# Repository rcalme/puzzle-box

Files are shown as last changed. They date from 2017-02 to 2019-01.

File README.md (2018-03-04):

# Custom Puzzle Box

This project is an attempt to build my skills in rapid prototyping, including laser cutting, 3D modeling and printing, and Arduino applications.

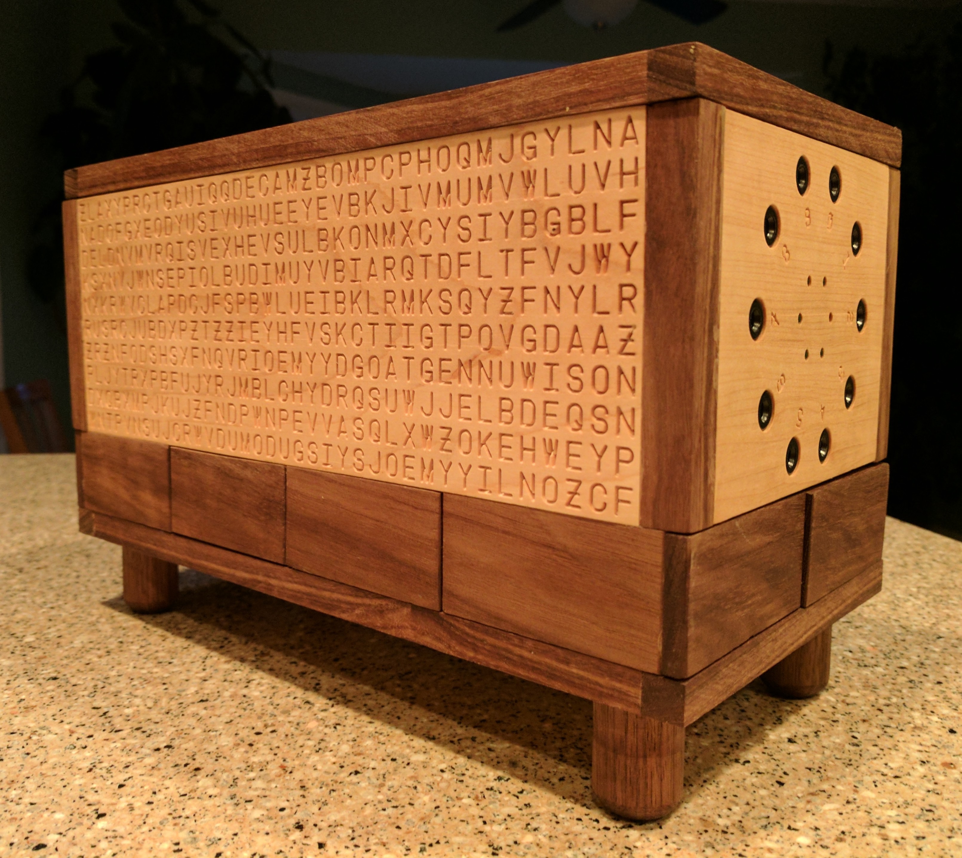
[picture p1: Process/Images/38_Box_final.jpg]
Final product


## Puzzles

* Magnet grid, with 30 positions, and 5 magnets (142,506 possible conbinations)
* Plug board with 10 numbered connectors, accepting 6 ordered pairs of digits (9,366,819 possible combinations)
* Screw panel, inaccessible without the correct tool
* Grille cipher, with double-sided grille
* Decryption cipher, with 5 unique two-sided gears (1,054,460 gear setup combinations)
  * 60 gear trio choices, 17,576 letter orientations
* Reversible drawer causing another drawer to open
* Hidden-in-plain-sight puzzles

## Video

Video of solution (http://www.youtube.com/watch?v=ibUV-bxcCZA)

## Design Process

You can see the progress in creating the physical box components on the [process readme].

[process readme]: </Process>

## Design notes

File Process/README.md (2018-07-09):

## Share your progress!
[Let me know](mailto:ryan.calme@gmail.com) if you've built one of these from my plans, and if so, what you needed to change so that I can make it better for others!

# Design and Manufacture Process

* This project was designed and built with mainly open-source softare.
* The specialized tools involved were available through the [TinkerMill] in Longmont, CO.

## Parts List
* See the [parts list]

## Hardware Used
* 80 Watt Laser Cutter ([Rabbit RL-80-1290])
* CNC Router ([Shopbot PRS Alpha])
* 3D Printer ([LulzBot Mini])
* Table Saw ([SawStop])
* Arduino ([Sparkfun Arduino Pro Mini 328 - 5V/16MHz])

## Software Used
* 3D Modelng ([SketchUp])
* 3D Slicing ([Cura])
* 2D Vector Design ([Inkscape])

## Puzzle Concepts

I did a lot of research on puzzles and puzzle box mechanisms while deciding what elements to include in this box.
Below are links to some content that inspired me:
* [Cipher gears]
* [Inverted drawer opening another]
* [Grille cipher]

## Initial prototype out of foam board:
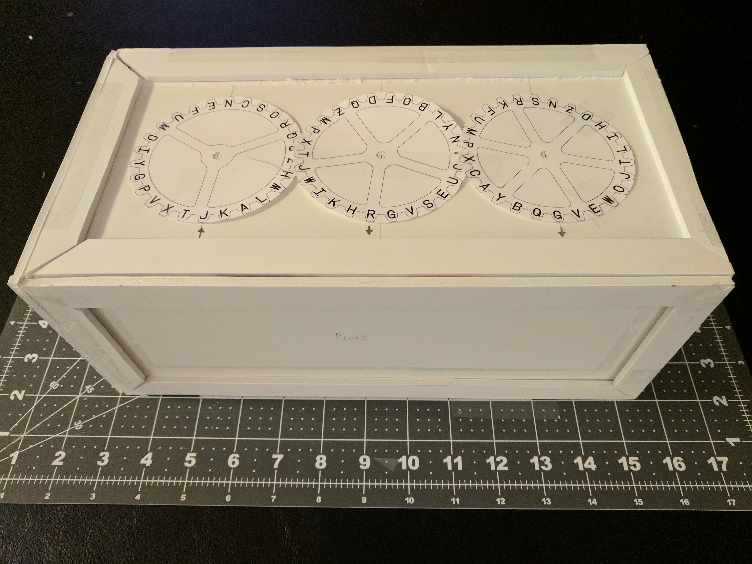
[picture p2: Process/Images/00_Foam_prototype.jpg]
Foam prototype
 

## Creating Cipher Gears

I wrote [Python code] to generate the order of the randomized letters on the five cipher gears, as well as to encrypt/decrypt messages.

The same was created as a [stand-alone web interface] by porting the code to Javascript to make it operable in a browser.

The gears themselves were first 3D printed, and later laser-cut in 1/4" red-stained maple, with the letters on the gear teeth engraved.
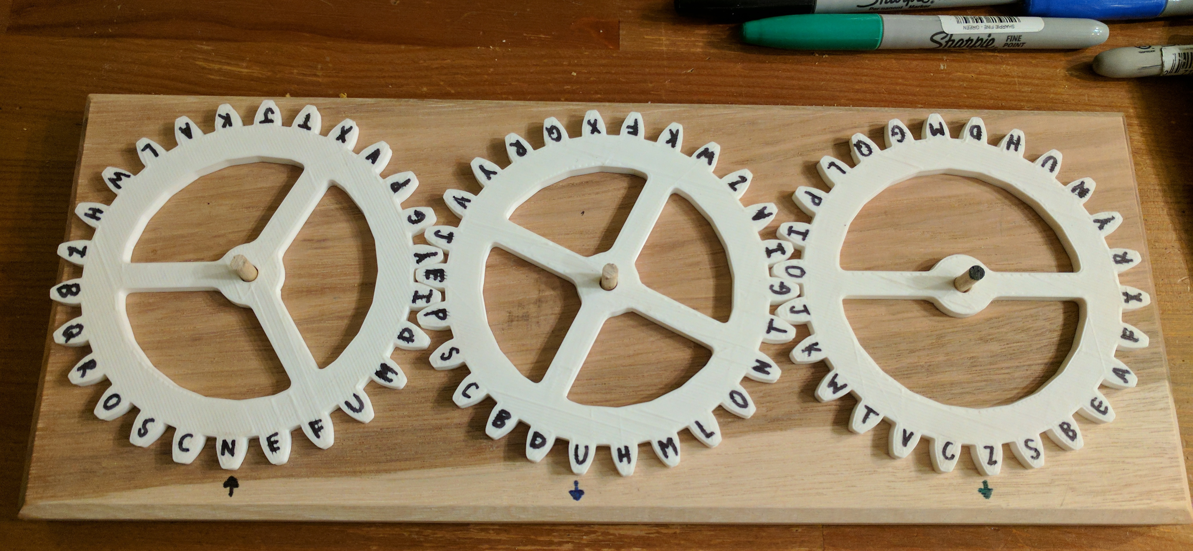
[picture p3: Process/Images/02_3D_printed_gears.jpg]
3D printed gears
 
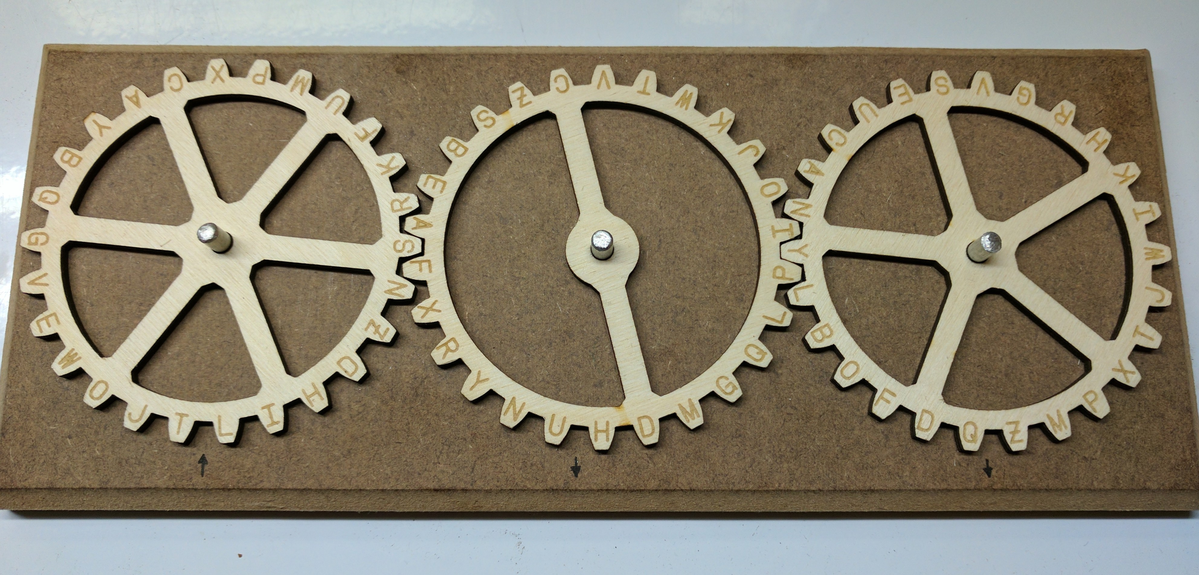
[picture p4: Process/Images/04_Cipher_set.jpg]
Cipher set
 
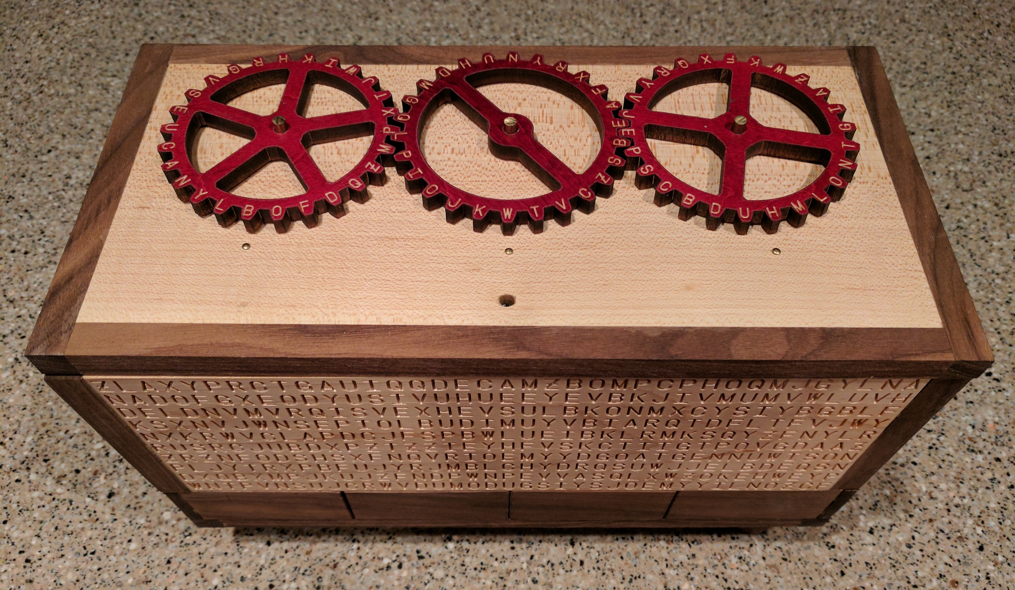
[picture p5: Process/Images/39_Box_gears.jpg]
Final gears
 
 
## Creating Magnet Puzzle

The magnet puzzle was always going to be a fixed-location puzzle, as the internal [reed switches] were wired in series.
The circuit is closed only when all switches were simultaneously closed.

The grid, and the symbols (in the [Magzetition font]) determine the locations of the five magnets to complete the hidden circuit, which itself supplies power to the [Arduino].

The outer layer is 1/4" maple, routed on a [ShopBot PRS Alpha], available at my local maker space.
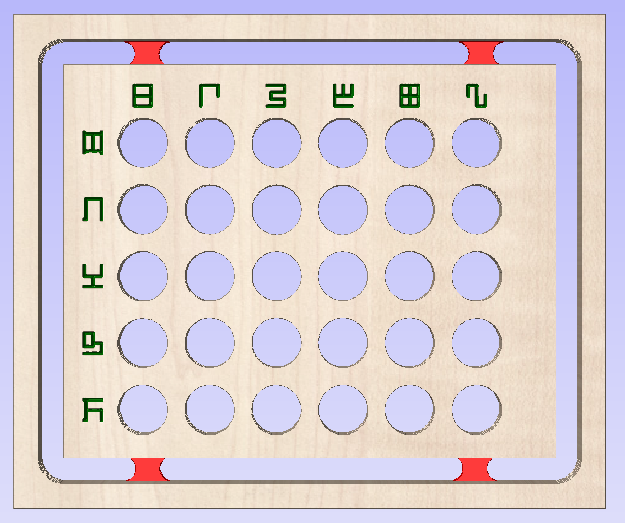
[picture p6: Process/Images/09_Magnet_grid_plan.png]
Magnet router plan
 
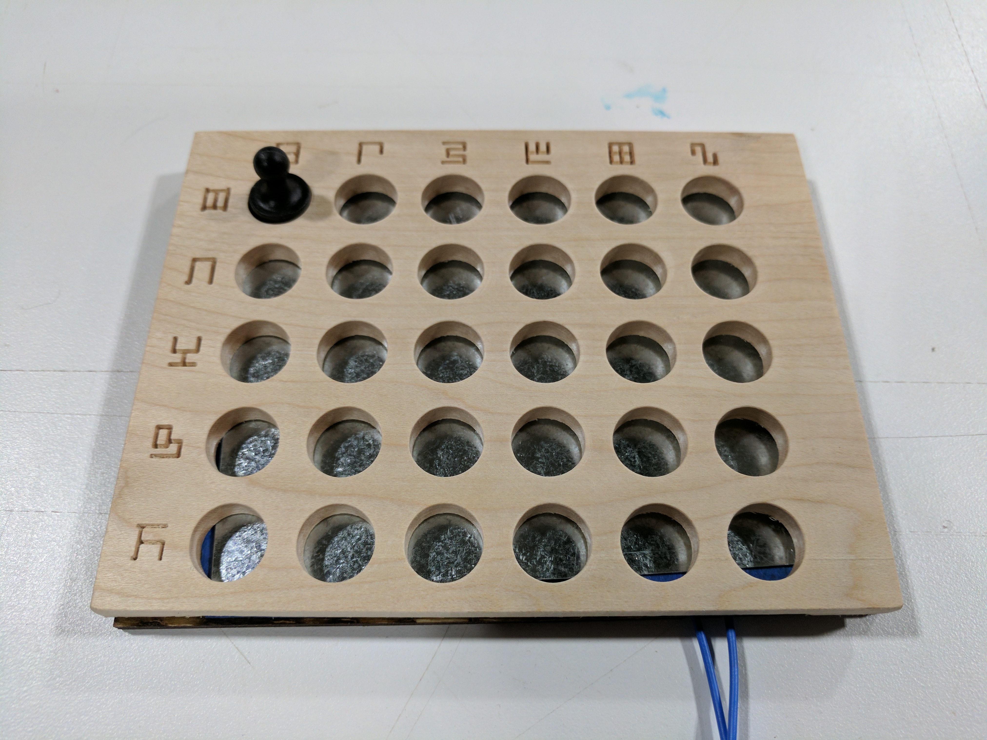
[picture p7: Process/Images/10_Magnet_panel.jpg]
Magnet puzzle outer
 

The inner layer is 1/8" Baltic birch, cut on an [80 watt Rabbit laser cutter], and wired up with these [mini reed switches].
 Magnet puzzle inner
 
## Creating Peg Board Puzzle

The peg board uses a jumper cable with banana connector ends, to detect the connection of any two-digit number pairs.
I set the code up to accept any combinations, and installed six LEDs to show progress when solving the puzzle's six ordered pairs of digits.

The [C++ code that probes this peg board] to detect any connection(s) using only 10 pins on an Arduino took some time to get right.

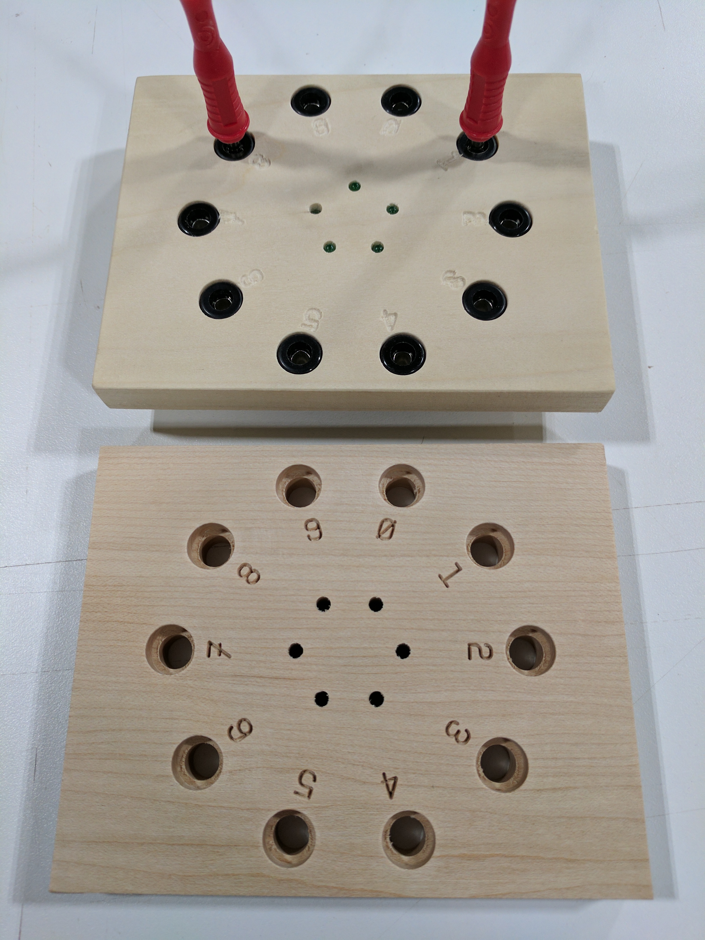
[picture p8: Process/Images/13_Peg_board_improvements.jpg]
Peg board improvements
 

## Creating the Back Panel Storage

The back panel is just an elaborate storage container for the [grille] mask plate.
The two faces are routed on a ShopBot, and sealed via security hex bit screws to make access difficult until the correct tool is located.

The grille itself is laser-cut out of two layers of 1/8" alder, sandwiching neodymium magnets.
The magnets ensure that the grille snaps into a single, specific position on the front of the box. When flipped to its 'B' side, the magnets are reversed, and again, the grille only snaps into a single (but different) location.

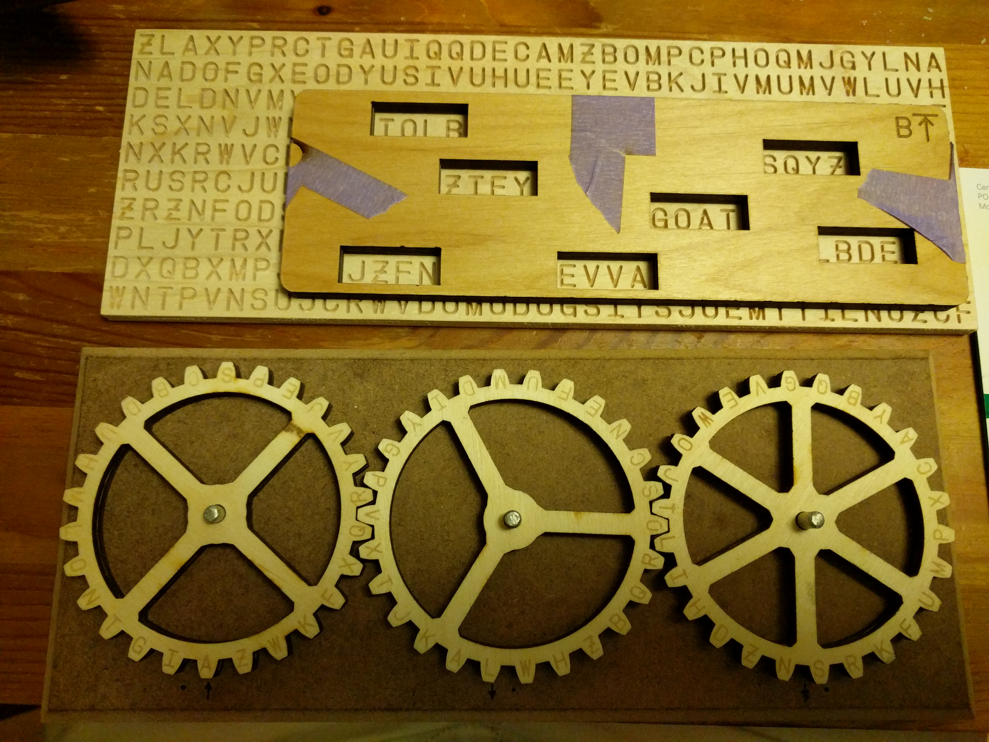
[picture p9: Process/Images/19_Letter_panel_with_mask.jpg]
mask plate in place
 
 
 ## Creating the Front Letter Panel
 
 The front letter panel is again routed on a ShopBot, with a field of random letters (in [Instruction font]).
 Only the letters highlighted with the grille are consequential (though encrypted).
 letter panel
 
 I wrote code to generate this letter field randomly, but consistently, as well as to calculate where to put the holes in the grille, such that when flipped from the 'A' side, to the 'B' side, there was no interference between the two patterns.

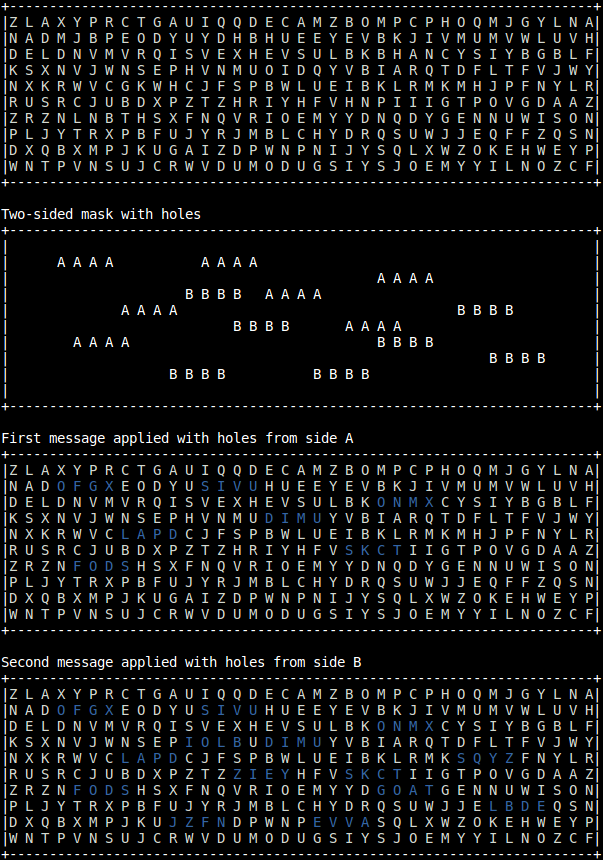
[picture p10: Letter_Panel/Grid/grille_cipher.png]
grille code output
 
 
 ## Creating the Drawers
 
 There are three operable drawers in the base of the box. 
 
 drawer assembly
 
 ### Left Drawer
 
 The left drawer is spring-loaded, and held in place by one of the legs of the box, which threads up through the base, into a hole in the drawer.
  When the leg is unscrewed, the drawer slides out.
  
 The drawer holds the magnets needed to complete the magnet puzzle on the left face.
 
 The threaded leg itself becomes a useful tool in solving the puzzle, as its tip is a star security bit, enabling access to the grille plate on the back of the box.
 
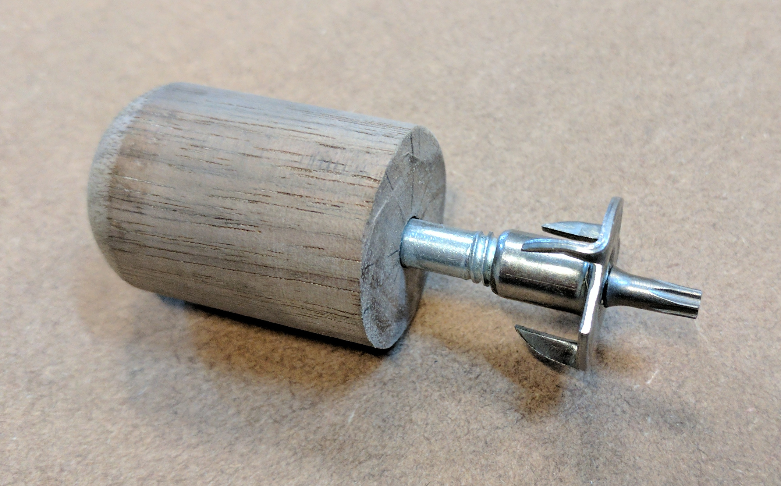
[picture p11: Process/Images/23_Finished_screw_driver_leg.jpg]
screw driver leg
 
 
 ### Front Drawer
 
 The front drawer holds two more cipher gears, needed to encrypt instructions for later in the puzzle.
 The drawer is released by turning the left drawer upside down, and pushing it back into its alcove.
 
 The latch mechanism was custom designed, and 3D-printed for this purpose.
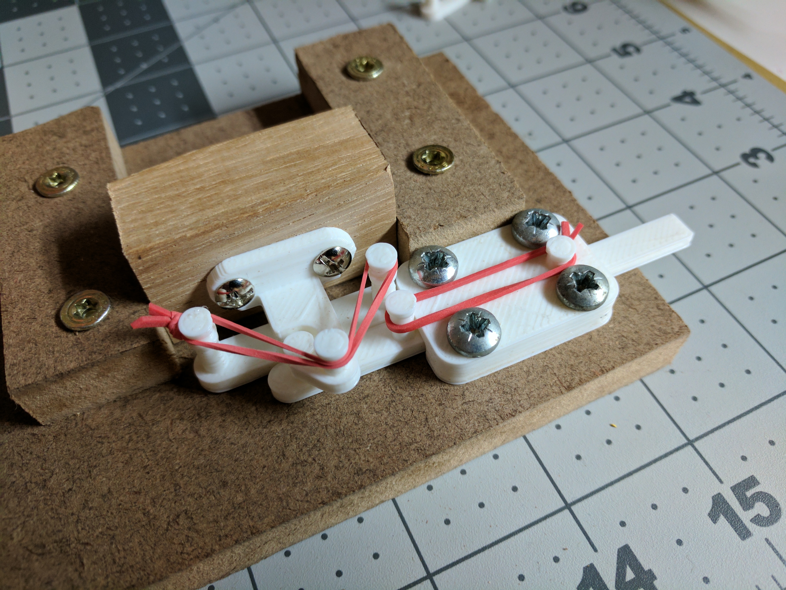
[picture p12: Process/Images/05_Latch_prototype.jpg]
latch mechanism
  
  
 ### Right Drawer
 
 The right drawer holds the banana jumper cable, and is released via a servo latch.
 The drawer is released as soon as the Arduino receives power (when the magnet puzzle is solved).
 
 ### Key Slider
 
 The key to unlock the box is finally accessible when it slides out the left side of the drawers via a servo.
 The sliding structure is made of two layers of laser-cut acrylic, and the brackets for the servo, and the slider are also custom designed and 3D-printed.
 
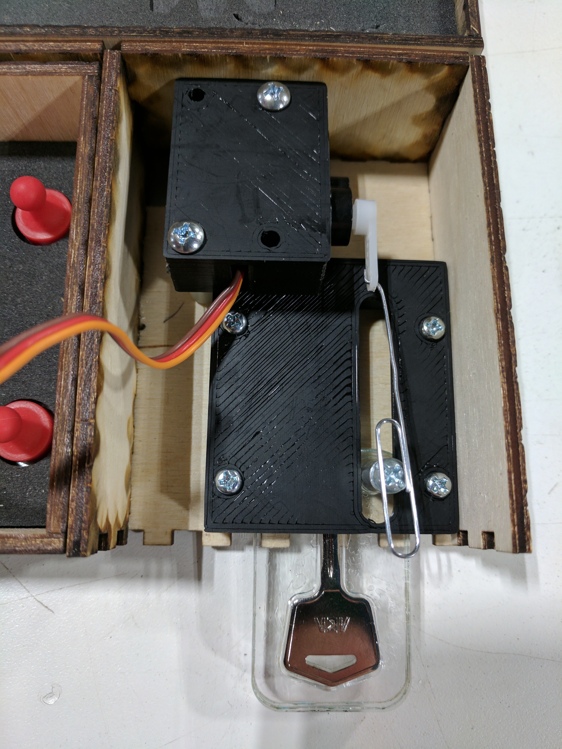
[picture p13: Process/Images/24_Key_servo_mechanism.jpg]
key slider
  
  
# Future improvements

I investigated the possibility of filling all the CNC-routed lettering with colored epoxy resin, and sanding it back down to flush with the face of the box. The results looked nice, but took quite a bit of time to get right.

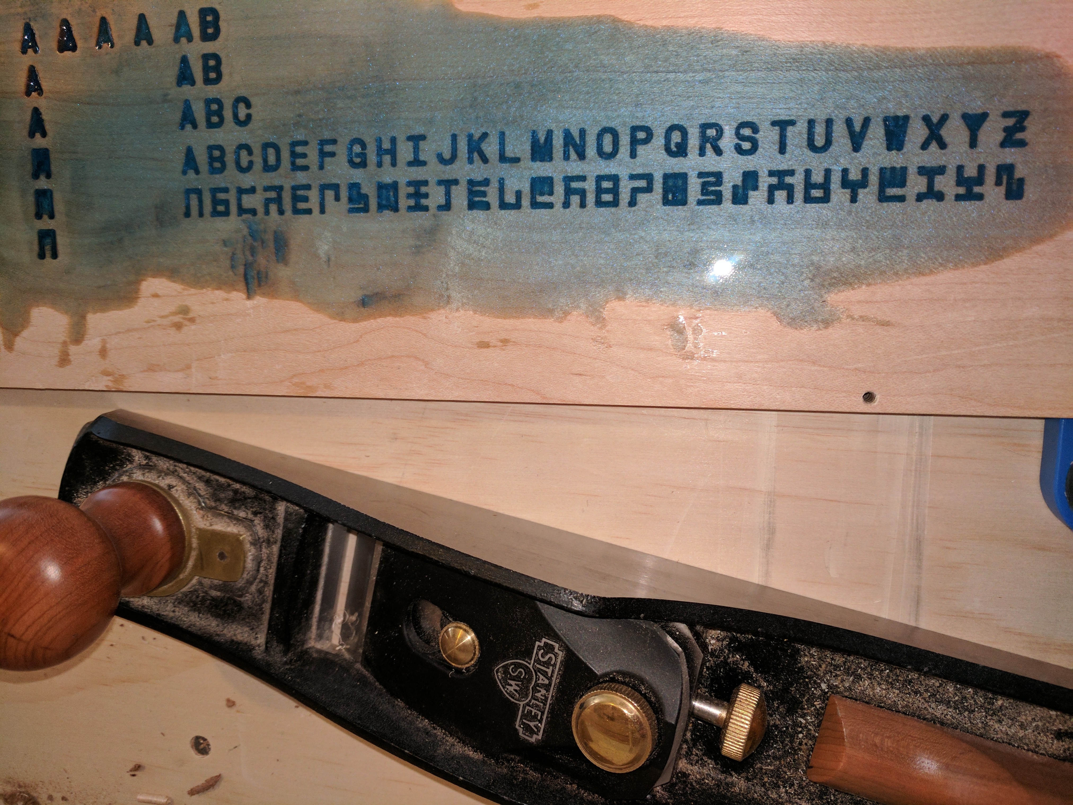
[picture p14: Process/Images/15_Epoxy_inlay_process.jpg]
epoxy resin
 
 epoxy finished
 
I also wrote the Arduino code to operate a speaker circuit with sound effects, but chose to cut this portion out due to lack of time, battery power draw, and available internal space.

   [Tinkermill]: <https://tinkermill.org>
   [Cipher gears]: <https://www.youtube.com/watch?v=hiOjqskDlS0>
   [Inverted drawer opening another]: <https://www.youtube.com/watch?v=foH1jnLvS_I>
   [Grille cipher]: <https://www.youtube.com/watch?v=tmgmOpaP_58>
   [Python code]: </Cipher_Gears/Translator/cryptex.py>
   [stand-alone web interface]: <https://rawgit.com/rcalme/puzzle-box/master/Cipher_Gears/Translator/cipherGears.html>
   [reed switches]: <https://en.wikipedia.org/wiki/Reed_switch>
   [Magzetition font]: <http://www.dafont.com/magzetician.font>
   [Instruction font]: <http://www.dafont.com/instruction.font>
   [Arduino]: <https://www.sparkfun.com/products/11113>
   [Sparkfun Arduino Pro Mini 328 - 5V/16MHz]: <https://www.sparkfun.com/products/11113>
   [ShopBot PRS Alpha]: <http://www.shopbottools.com/mProducts/prSalpha.htm>
   [80 watt Rabbit laser cutter]: <http://www.rabbitlaserusa.com/laser_RL1290.html>
   [Rabbit RL-80-1290]: <http://www.rabbitlaserusa.com/laser_RL1290.html>
   [mini reed switches]: <https://www.sparkfun.com/products/10601>
   [C++ code that probes this peg board]: </Arduino/Puzzle_Box>
   [grille]: <https://en.wikipedia.org/wiki/Grille_(cryptography)>
   [LulzBot Mini]: <https://www.lulzbot.com/store/printers/lulzbot-mini>
   [SawStop]: <http://www.sawstop.com>
   [SketchUp]: <http://www.sketchup.com>
   [Cura]: <https://www.lulzbot.com/cura>
   [Inkscape]: <https://inkscape.org/en>
   [parts list]: <PartsList.md>

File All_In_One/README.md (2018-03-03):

# All in one files

These files are prepared so that you can cut/print all the parts for a single tool in one go.
* **3D** includes a `.stl` file with all the necessary 3D-printed parts on one build plate.
* **Laser** includes a few `.dxf` files for laser cutting, one per material.
* **CNC** includes a `.dxf` file for a CNC router.

Assembly instructions can be found here

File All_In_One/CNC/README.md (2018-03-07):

# CNC Files

Depending upon your CNC, and software toolchain, you're likely to have to edit 
these files before you can send anything to your machine.

I cut this out of a 1x6 maple board, because it's what I had on hand.

The initial dimensions were 5.5" wide, 0.75" thick, and 48" long.

The thickest parts are 0.5", so the first pass is to use a flycutter bit to plane 
down the surface. This makes sure that it's both flat, and the correct thickness.

Cutting layout
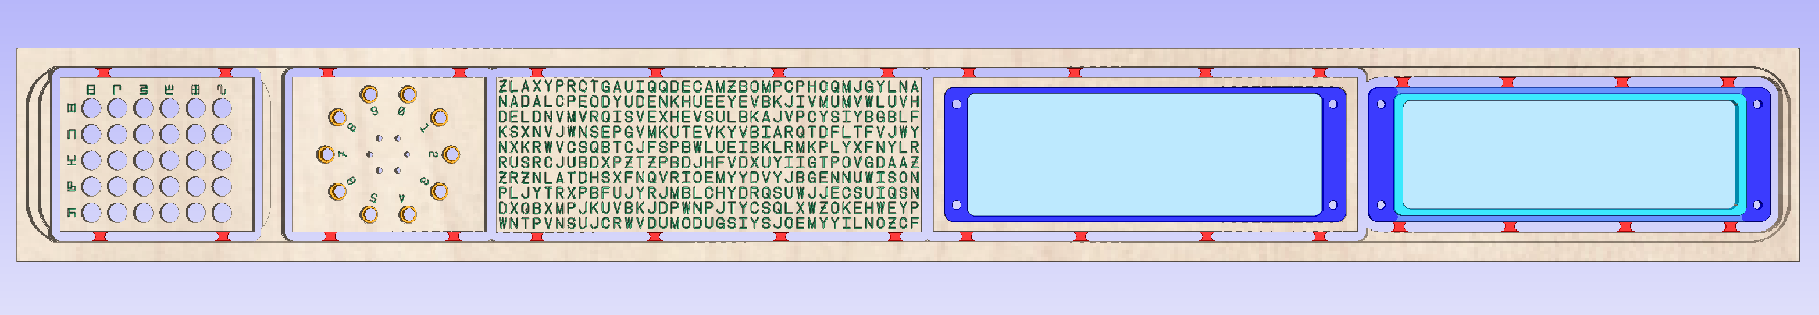
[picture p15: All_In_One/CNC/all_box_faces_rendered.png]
Rendered result


## Router Bits Used
Bit Type | Bit Diameter | Used For
---------|--------------|---------
Flycutter|2.0"          |Planing board surface to 0.5" and 0.25"
Endmill  |0.125" (1/8") |Cutting small through-holes (LEDs, screw holes)
Endmill  |0.25"  (1/4") |Cutting screw panel depths, cutting out panels
30° V-bit|0.125" (1/8") |Cutting letters (use a sharp bit, go very slowly)

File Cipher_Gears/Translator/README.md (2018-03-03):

# Encrypting/Decrpyting messages

The setup for encrypting and decrypting messages involves two parts:
1. Placing the gears in the right spoke order (2, 4, 5), for example
1. Turning each gear individually to match a key of an equal number of letters to the number of gears used.

An example [can be found here](https://rawgit.com/rcalme/puzzle-box/master/Cipher_Gears/Translator/cipherGears.html) (random seed is set to the default in this code).

[cipher.py](cipher.py) is provided to encrypt and decrypt arbitrary messages. Use it as follows:
```
> ./cryptex.py --gears 2 4 6 --key YAY --seed 12345 --encrypt "This is a secret message"
JBHQ HQYQ TADH JUTQ VMFH

> ./cryptex.py --gears 2 4 6 --key YAY --seed 12345 --decrypt "JBHQ HQYQ TADH JUTQ VMFH"
THIS ISAS ECRE TMES SAGE
```

**NOTE:** providing a random seed overrides the default, and will result in generated letter 
combination on the gears that differ from those in this git project. Take care to modify those files
before cutting parts if you intend to use a different seed.

You can print the orientation of the letters on the gears generated by this utility by adding the `--show` flag:
```
> ./cryptex.py --gears 2 4 6 --key YAY --seed 12345 --decrypt --show "JBHQ HQYQ TADH JUTQ VMFH"
2-spoke: YNZMSJBXUQRVHCDLEIGTAKPOFW
4-spoke: AJGLYPOEFUCBRVISKQWMXTHZND
6-spoke: YXQAPRHLMSIZENUJBFGTCKVDWO

THIS ISAS ECRE TMES SAGE

```

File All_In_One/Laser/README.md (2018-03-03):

## Laser Files

### Cipher Gears
The gears are cut from of 1/4" wood. I've used red-stained maple, as well as alder, which can be purchased 
in small quantity from [Colorado Heirloom](http://www.coloradoheirloom.com/products/160/Wood-Strip-br/-4-5-x-14-5-x-3/16-or-1/4)

### Drawers and Box Shell
This portion of the box is cut from 1/8" (3mm) birch plywood.

### Grille Cipher
The grille for the cipher is composed of two sandwiched 1/8" (3mm) pieces of wood, which can also be purchased from
[Colorado Heirloom](http://www.coloradoheirloom.com/wood-strip)

### Key Slider
This portion can be cut from 1/8" (3mm) acrylic, or wood.

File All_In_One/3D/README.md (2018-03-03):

## 3D-Printed Parts

This file contains all of the 3D-printed parts required.
* Latch hook for the right drawer
* Latch mechanism that allows the left drawer to open the center drawer
* Servo bracket
* Slider mechanism for the key drawer

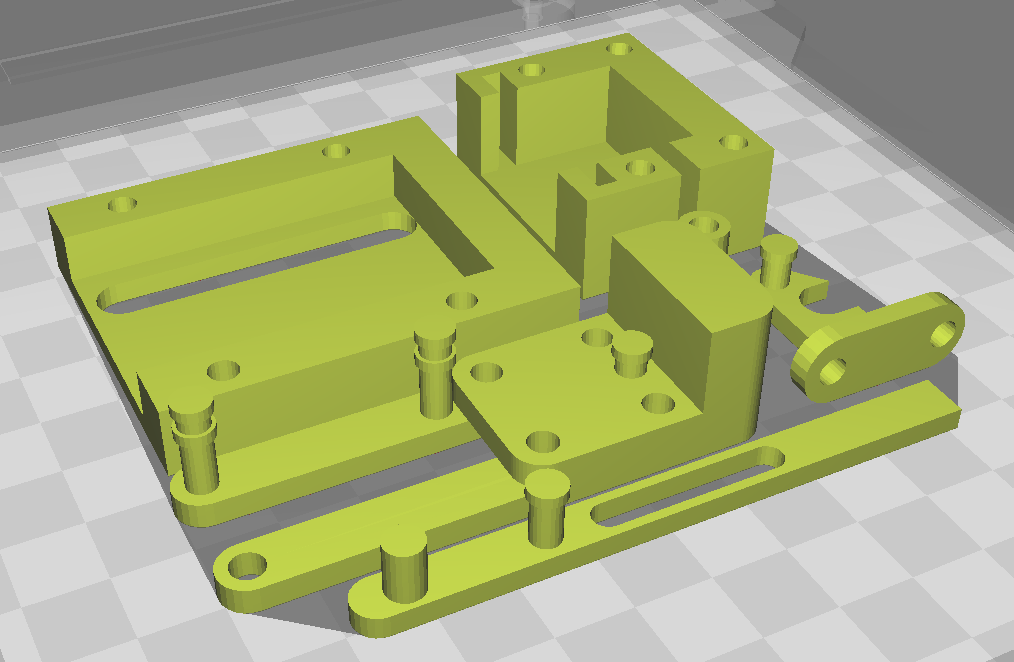
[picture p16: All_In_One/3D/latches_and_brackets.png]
Rendering of latches and brackets on build plate


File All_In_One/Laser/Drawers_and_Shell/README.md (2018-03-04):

## Drawers and Box Shell

These parts are all laid out on one sheet, but may have to be modified if you have a smaller form-factor laser cutter.

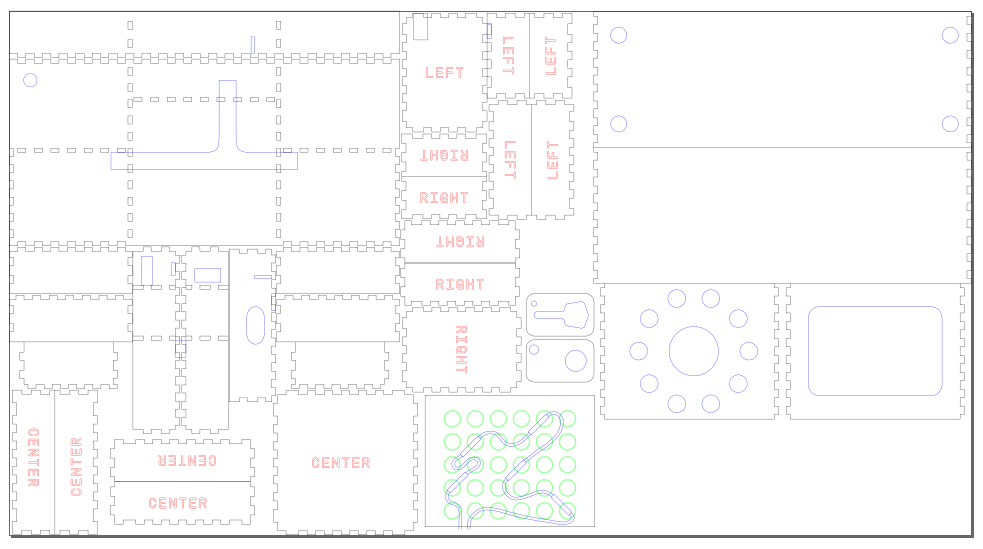
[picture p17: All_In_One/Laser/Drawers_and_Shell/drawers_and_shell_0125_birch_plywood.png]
Drawer parts


### Process
These pieces are pretty simple to cut and etch. I've made different colors for etching, cutting internal holes, and cutting external outlines.

I used the following laser power/speed settings:
* Etch
  * Speed: 300mm/s
  * Power: 18% of 80W machine (15 watts)
* Cut
  * Speed: 15mm/s
  * Power: 40% of 80W machine (32 watts)

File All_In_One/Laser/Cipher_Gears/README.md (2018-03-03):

## Cipher Gears

**NOTE:** These gears were generated with the code [here](/Cipher_Gears/Translator/cryptex.py), using a fixed random seed.
If you change the order of the letters by using a different random seed, obviously these 
files will need to be modified before cutting/etching.

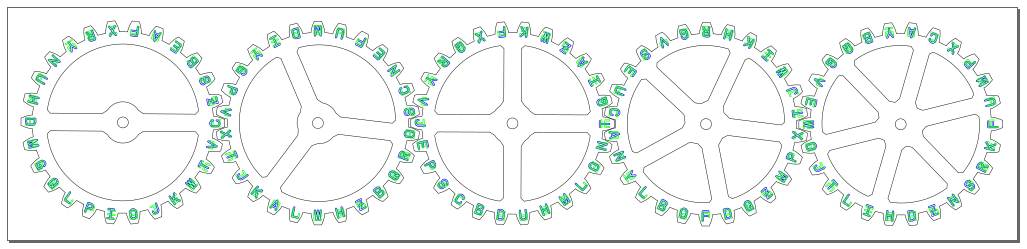
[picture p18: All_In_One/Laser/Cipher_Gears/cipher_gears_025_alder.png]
Cipher Gears


### Process
Since these are two-sided gears the order is pretty important:
1. (Optional) Cover both sides of the wood with low-tack painter's tape, or transfer paper to prevent charring
1. Etch one side of the gears (the two sides are different colors/layers)
1. Cut the gear outlines
1. Flip over the gears _without moving the frame from which they've been cut_, and making sure they remain in their same positions
1. Etch the other side of the gears

I used the following laser power/speed settings
* Etch
  * Speed: 400mm/s
  * Power: 18% of 80W machine (15 watts)
* Cut
  * Speed: 15mm/s
  * Power: 70% of 80W machine (56 watts)

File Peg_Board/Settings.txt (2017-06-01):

0.54"

Letters
  Bit: 0.125, 30 deg, 0.1 Depth, 4%/25%, 18K RPM, 0.15 ips, 0.2 ips plunge
  Depth: Flat @ 0.1
  Type: V-Carve  

LED
  Bit: 0.125
  Depth: Through
  Type: Pocker
  Passes: 4

Socket
  Bit: 0.25
  Depth: 0.2
  Type: Pocket
  Passes: 2

Socket Holes
  Bit 0.25
  Depth: Through
  Type: Pocket
  Passes: 4

Outer Cut
  Bit 0.25
  Depth: Through
  Type: Profile
  Tabs: 4 @ 0.1 tall, 0.25 wide

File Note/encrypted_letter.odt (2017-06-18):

I see that you have the tools to proceed The artifact awaits you above the home of those with cloven hooves

bgya hyxl kdry xoyl sahd asvl acpd qayv hyyz plbw xnhz dzbl vxar xiao ylsa sdoa awhy agym blsn wdja fyad jav

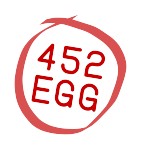
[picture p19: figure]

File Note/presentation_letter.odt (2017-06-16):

A unique item has fallen into my possession. I fear that I will not be able to keep it safe. You know too well the many who pursue my knowledge. I am giving it to you in the hopes that you will be able to keep it secret.

You should already have everything you need to unlock the secrets within. I trust in your skill - and your discretion.

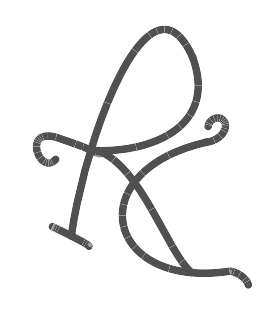
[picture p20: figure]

Our curiosity has brought us here. Only our wits can save us now.

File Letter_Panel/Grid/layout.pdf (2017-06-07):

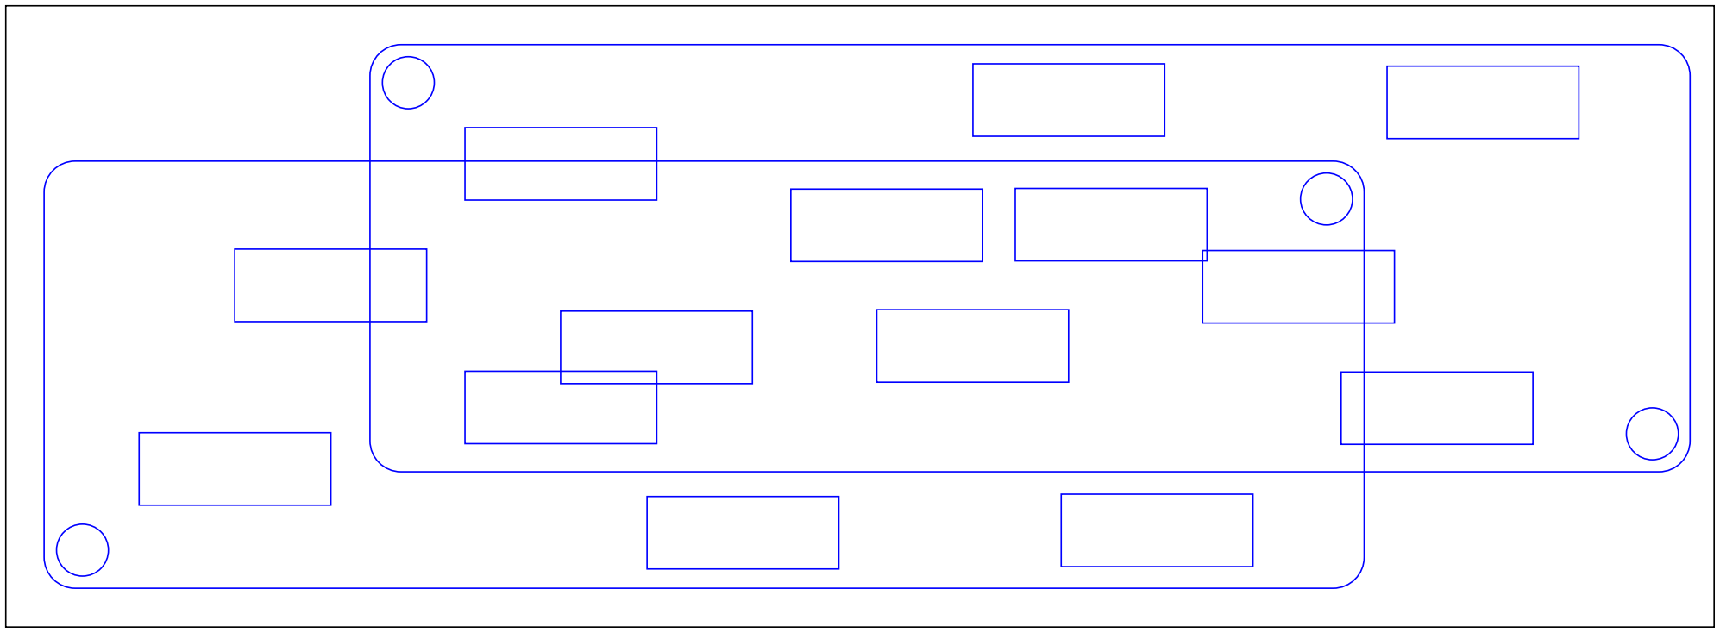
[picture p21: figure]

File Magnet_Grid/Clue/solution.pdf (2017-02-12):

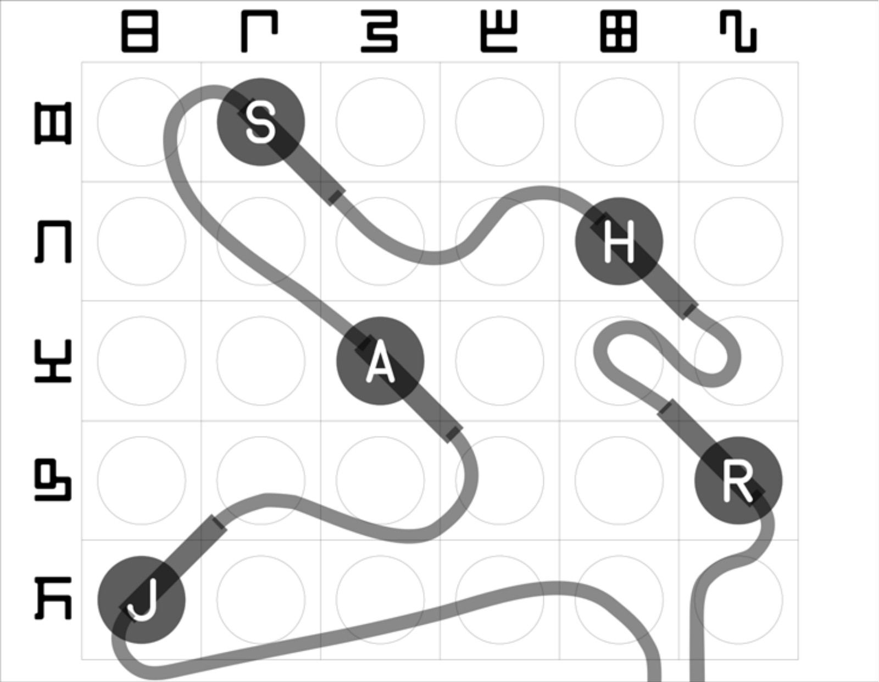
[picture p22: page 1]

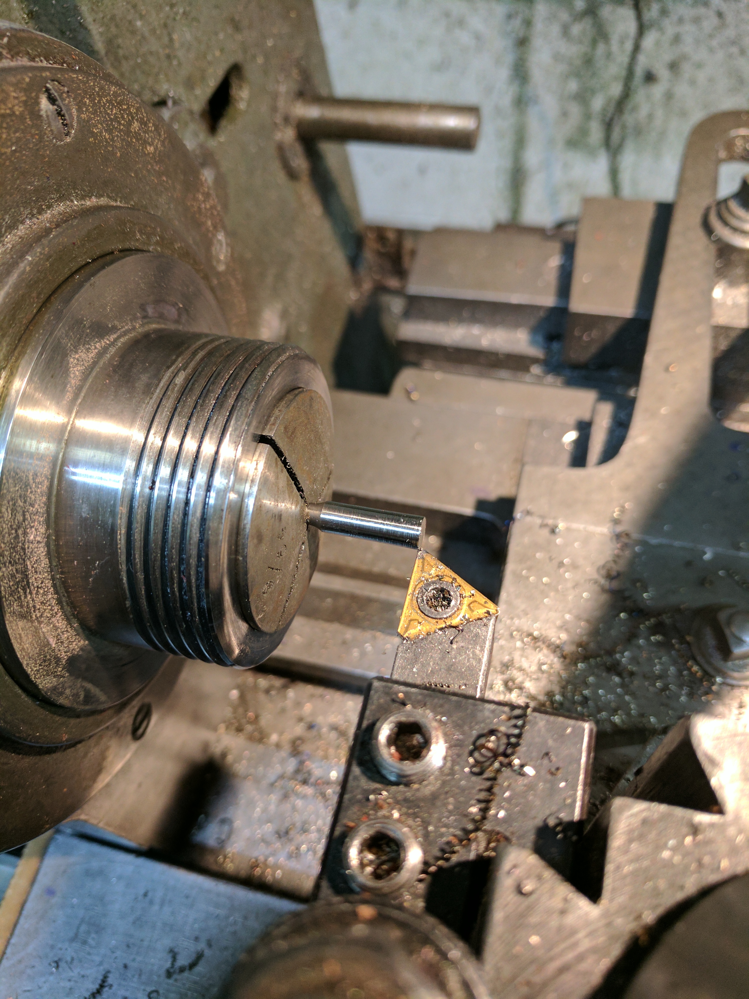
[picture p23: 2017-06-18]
Process/Images/20_Milling_driver_bit.jpg

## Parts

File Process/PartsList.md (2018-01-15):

# Parts List
All of the parts necessary to build this box should be listed here.

Everything ***should*** come to **under $250**, but it'll depend on the wood you choose, and your access to tools.

I'll admit that as of now, I've only built the one, but I documented everything pretty thoroughly as I went.
Feel free to contact me with questions.

## Parts
| Quantity | Cost Per	| Cost Total | Description | Number Used | Link | Note |
| --- | --- | --- | --- | --- | ---- | ---- |
| 1 | $15 | $15 | 48 Map Magnets | 5 | [Amazon](https://www.amazon.com/Magnets-48-Multi-Color-Magnetic-Style/dp/B014HKZA1W) | Comes with 12 each of 4 colors. | 
| 1 | $6 | $6 | 500 Small Rubber Bands | 2 | [Amazon](https://www.amazon.com/gp/product/B00Y16H9LM) |  | 
| 1 | $11 | $11 | Miniature Cam Lock | 1 | [Amazon](https://www.amazon.com/gp/product/B01HFNYH8A) | Comes with 2 keys. | 
| 1 | $19 | $19 | 10 Micro Servos | 2 | [Amazon](https://www.amazon.com/gp/product/B00ZEDRR3Q) | Come with horns, mounting screws. | 
| 1 | $8 | $8 | Neodynium Magnets | 4 | [Amazon](https://www.amazon.com/Linlinzz-Personalized-Multi-Use-Whiteboard-Refrigerators/dp/B01MZ6EJE2) | Comes with 35. | 
| 1 | $3 | $3 | 2 4xAA Battery Holders | 1 | [Amazon](https://www.amazon.com/gp/product/B00H8WI6HC) | Comes with 2. | 
| 1 | $8 | $8 | Security Bit Set | 1 | [Amazon](https://www.amazon.com/Mangocore-Security-Electric-Screwdrive-Magnetic/dp/B01I64IYJ0) | Will have to machine. | 
| 1 | $3 |  | 1/2" Security Screws | 4 |  | For back plate. Match the security bit you buy. | 
| 1 | $3 |  | Small Binding Posts | 4 |  | AKA "Chicago Screws". Security screws thread into these. | 
| 1 | $12 | $12 | 300 Multi-color 3mm LEDs | 5 | [Amazon](https://www.amazon.com/CO-RODE-Emitting-Assorted-300-Pack/dp/B00UWBJM0Q) | Any 3mm LEDs should suffice. | 
| 1 | $10 | $10 | 5v Arduino Pro Mini | 1 | [Sparkfun](https://www.sparkfun.com/products/11113) |  | 
| 5 | $2 | $10 | Magnetic Reed Switch | 5 | [Sparkfun](https://www.sparkfun.com/products/10601) |  | 
| 1 | $1 | $1 | Ribbon Cable | 1 | [Sparkfun](https://www.sparkfun.com/products/10649) | Doesn't have to be 10-wire. Helps with wire management. | 
| 2 | $5 | $10 | Banana Cable | 2 | [Digikey](https://www.digikey.com/product-detail/en/cal-test-electronics/CT2060-25-2/BKCT2060-25-2-ND) | One in the puzzle, one needed to reset. | 
| 10 | $1 | $7 | Banana Jacks | 10 | [Digikey](https://www.digikey.com/product-detail/en/cinch-connectivity-solutions-johnson/108-0903-001/J152-ND) | Discount if purchased in quantity. | 
| 1 | $3 | $3 | 3/16" Brass Rod | 1 | [Home Depot](https://www.homedepot.com/p/3-16-in-x-36-in-Zinc-Plated-Round-Rod-802287/204273957) | Doesn't have to be brass. Only need a few inches. | 
| 1 | $1 | $1 | Estucheon Pins | 3 | [Home Depot](https://www.homedepot.com/p/Everbilt-18-x-3-4-in-Brass-Escutcheon-Pins-0-5-oz-Pack-801294/204274028) | Any size/metal/length. | 
| 1 | $1 | $1 | Brass Washers | 3 | [Home Depot](https://www.homedepot.com/p/Everbilt-10S-Brass-Flat-Washer-10-Pack-802671/204276457) |  | 
| 1 | $1 | $1 | 1/4"x20 Hanger Bolt | 1 | [Home Depot](https://www.homedepot.com/p/Crown-Bolt-1-4-in-20-tpi-x-2-in-Stainless-Hanger-Bolt-48488/203537698) | Length will depend on legs. | 
| 1 | $1 | $1 | 1/4"x20 Tee Nut | 1 | [Home Depot](https://www.homedepot.com/p/Everbilt-1-4-in-20-tpi-x-5-16-in-Zinc-Plated-Tee-Nut-4-per-Pack-802301/204274194) |  | 
| 1 | $11 | $11 | Steel Sheet (Magnetic) | 1 | [Home Depot](https://www.homedepot.com/p/M-D-Building-Products-12-in-x-24-in-22-Gauge-Weldable-Sheet-56066/202091749) | Need 5"x5". | 
| 1 | $2 | $2 | Small Hinges | 2 | [Home Depot](https://www.homedepot.com/p/Everbilt-1-in-Zinc-Plated-Non-Removable-Pin-Narrow-Utility-Hinges-2-Pack-15161/202034166) | Your choice of size/style. | 

## Materials
| Quantity | Cost | Description | Link | Note |
| --- | ---- | --- | ---- | ---- |
| 1 | $5 | 1/4" Laser-etchable Wood | [Colorado Heirloom](http://www.coloradoheirloom.com/products/160/Wood-Strip-br/-4-5-x-14-5-x-3/16-or-1/4) | For gears. | 
| 1 | $5 | 1/8" Laser-etchable Wood | [Colorado Heirloom](http://www.coloradoheirloom.com/wood-strip) | For grille cipher sandwich) | 
| 1 | $12 | 1/4" Laser-safe Foam | [Foam Factory](http://www.thefoamfactory.com/closedcellfoam/cross-linked-polyethylene-foam.html) | Cross-Linked Polyethelene. For gear drawer insert. | 
| | | 1/2" Maple |  | For all other faces. | 
| | | 1/4" Maple |  | For magnet puzzle face. | 
| | | 1/2" Walnut |  | For border. | 
| | | 1" Walnut Dowel |  | For feet. | 
| | | 1/8" (3mm) Birch Plywood |  | For laser-cut drawers/interior. | 
| | | 1/8" Acrylic |  | For the key-holder - could also be wood. | 
      
## Consumables
| Item | Note |
| ---- | ---- |
| Patience | A lot. |
| Soldering Iron | |			
| Solder | |
| Hook-up Wire | |
| Heat-shrink Tubing | |
| 220 Ohm Resistors | For LEDs - Modify depending upon your LEDs. |
| Ballpoint Pen Springs | |
| USB FTDI Arduino Cable | [Sparkfun](https://www.sparkfun.com/products/9718) - To Program the Arduino. |
| Male 0.1" Headers | [Sparkfun](https://www.sparkfun.com/products/116)	|
| AA Batteries | |
| Assorted Screws | |
| Wood Glue | |

## Expensive Tools
| Item | I Used | Note |
| ---- | ---- | ---- |
|	3D Printer | [Lulzbot Mini](https://www.lulzbot.com/store/printers/lulzbot-mini) | Printed in [PLA](https://www.lulzbot.com/store/filament/polylite-pla) |
|	CNC Router | [ShopBot PRS Alpha](http://www.shopbottools.com/mProducts/prSalpha.htm) | Don't need a very large work surface for this project. |
|	Laser-etcher/cutter | [Rabbit Laser 80-Watt](http://www.rabbitlaserusa.com/laser_RL1290.html) | Cut/Engrave Settings are saved in files. |
|	Table Saw | [SawStop](http://www.sawstop.com/table-saws/by-model/industrial-cabinet-saw) | |
|	Metal Lathe | Generic | To turn the security bit down in diameter. |

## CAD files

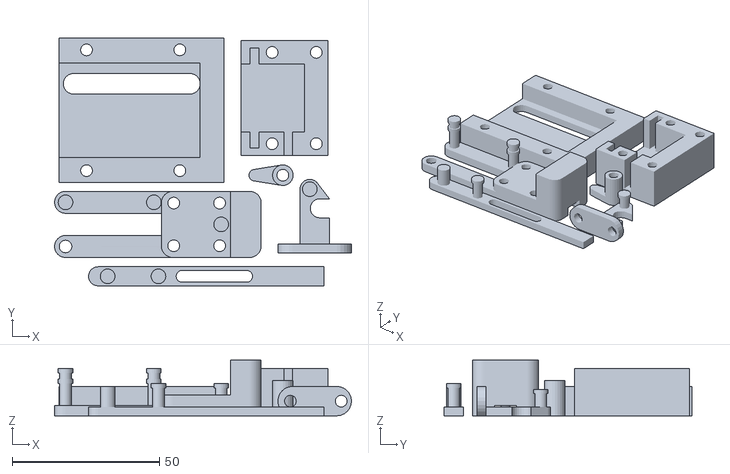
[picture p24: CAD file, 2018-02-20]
All_In_One/3D/latches_and_brackets.stl
100.9 x 84.1 x 18.9

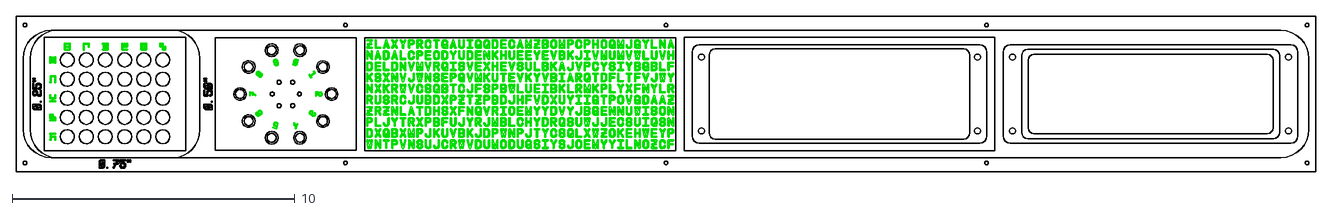
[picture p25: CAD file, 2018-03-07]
All_In_One/CNC/all_box_faces_075_maple.dxf
46.0 x 5.50

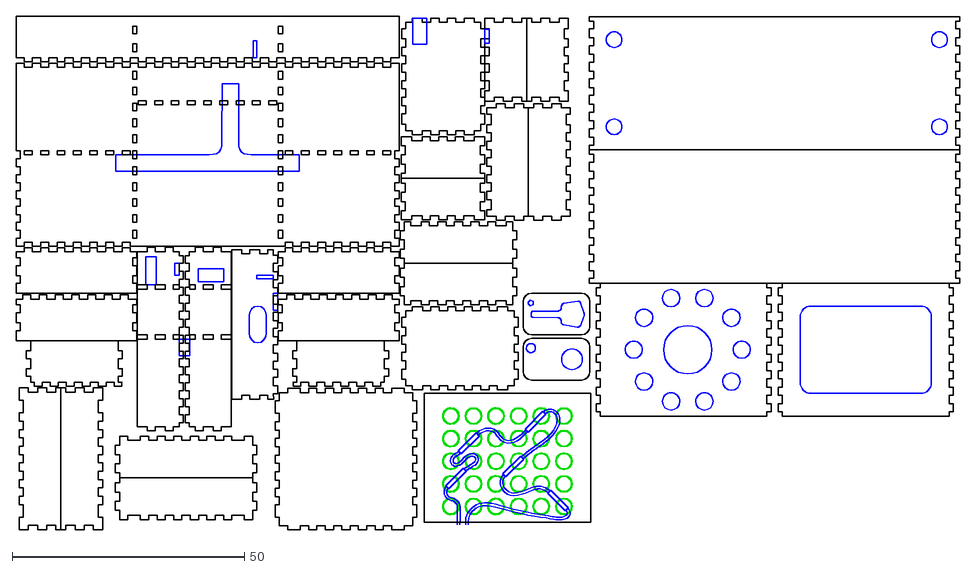
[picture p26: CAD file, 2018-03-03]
All_In_One/Laser/Drawers_and_Shell/drawers_and_shell_0125_birch_plywood.dxf
203.1 x 110.6

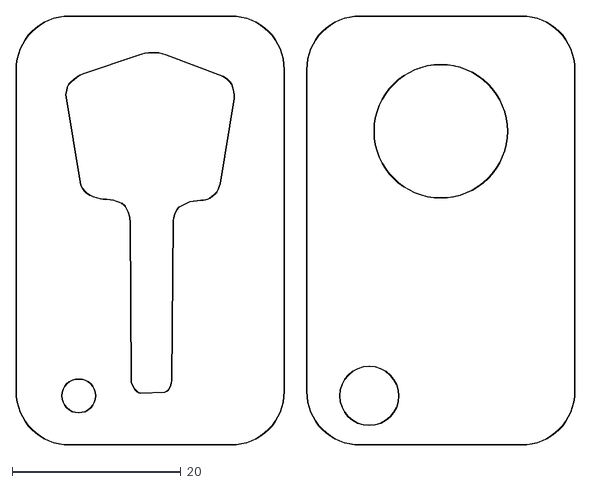
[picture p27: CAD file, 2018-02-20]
All_In_One/Laser/Key_Slider/key_slider_0125_acrylic.dxf
66.2 x 50.8

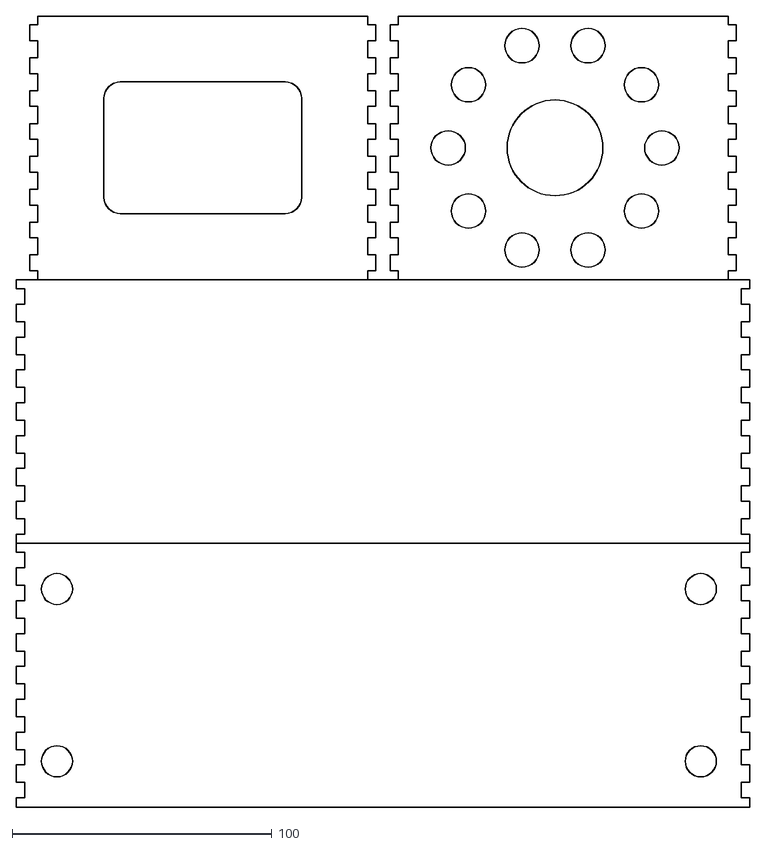
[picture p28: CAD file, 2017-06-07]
Box_Shell/box_shell.dxf
282.6 x 304.8

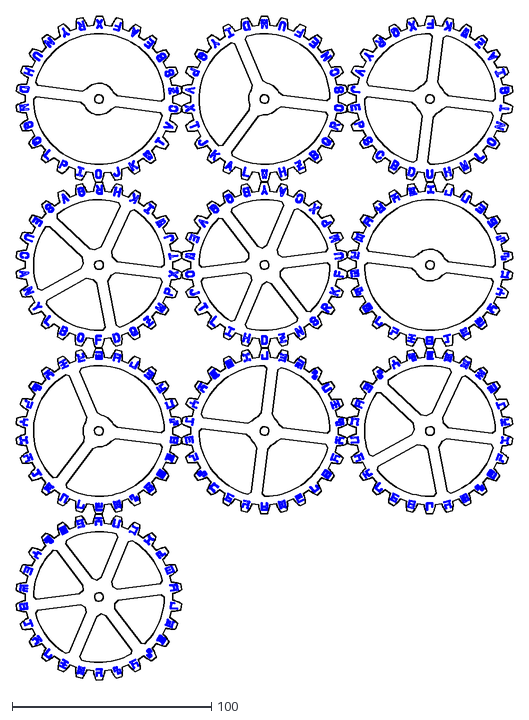
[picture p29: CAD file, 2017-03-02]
Cipher_Gears/All_Gears/all_gears.dxf
249.3 x 333.4

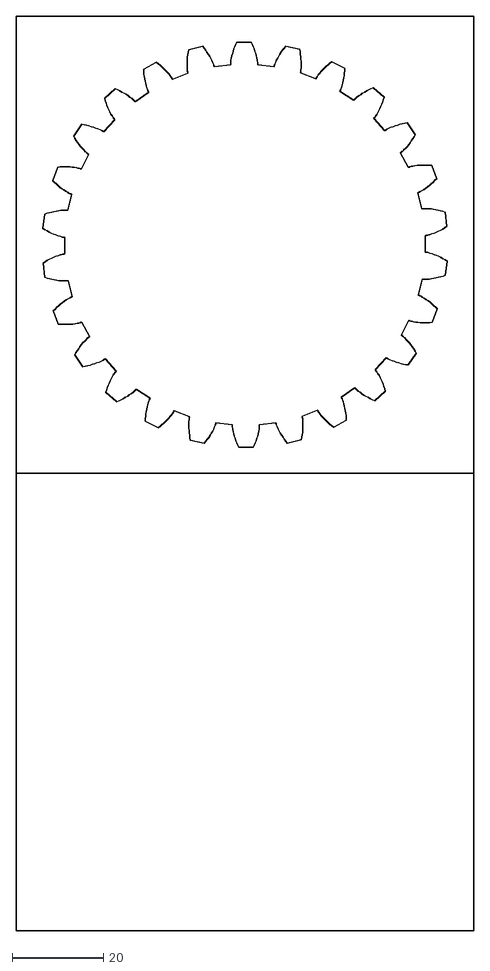
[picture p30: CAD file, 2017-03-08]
Cipher_Gears/Foam_Cutout/gear_cutout.dxf
100.3 x 200.6

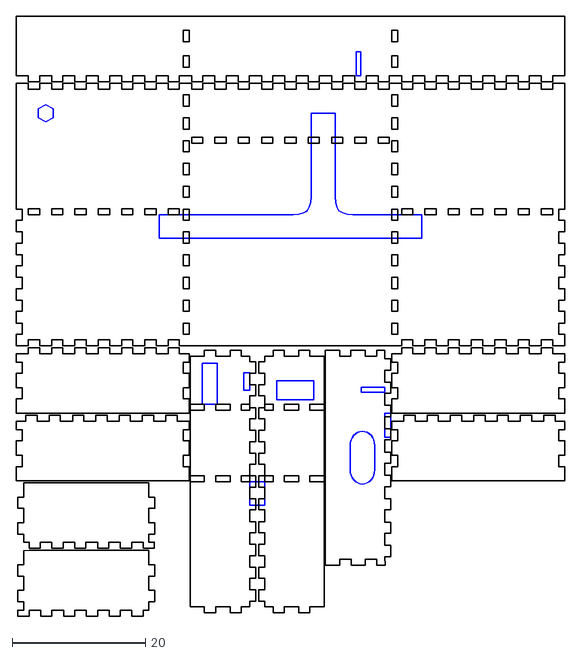
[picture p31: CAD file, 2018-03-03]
Drawers/Base/drawer_base.dxf
82.4 x 90.2

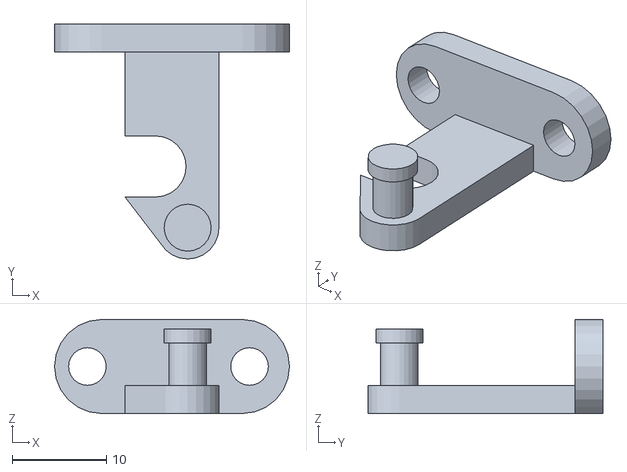
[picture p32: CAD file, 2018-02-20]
Drawers/Center/hook.stl
25.0 x 25.0 x 10.0

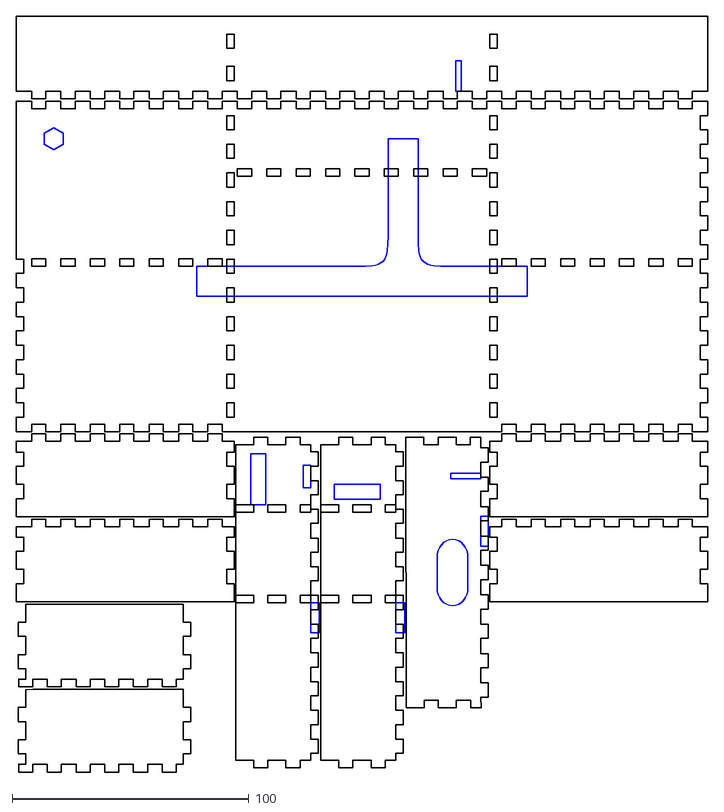
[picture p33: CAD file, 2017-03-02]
Drawers/Drawer_Base/drawer-base.dxf
292.1 x 319.5

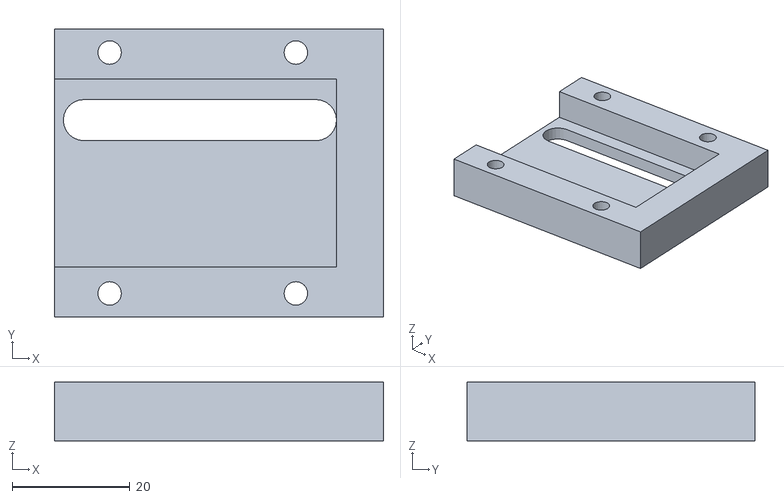
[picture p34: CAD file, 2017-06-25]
Drawers/Key/key_guide.stl
56.0 x 49.0 x 10.0

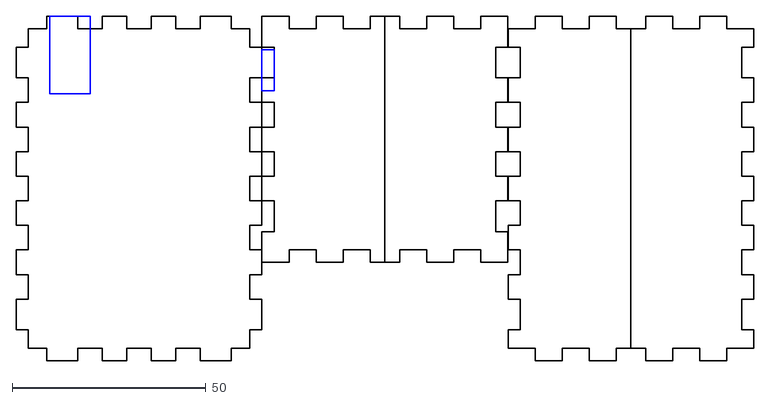
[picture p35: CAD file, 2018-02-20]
Drawers/Left/left_drawer.dxf
190.6 x 88.9

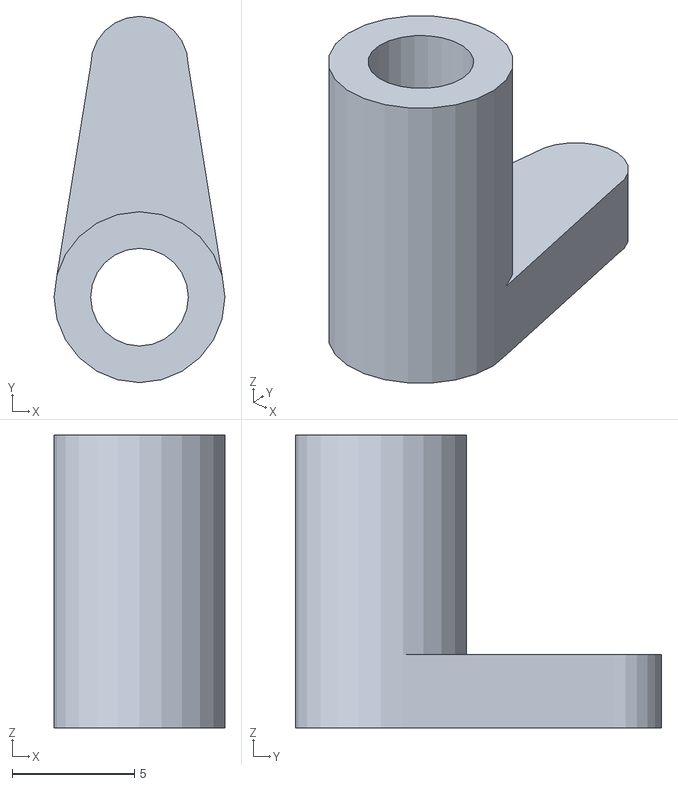
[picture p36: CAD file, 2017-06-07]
Drawers/Right/catch.stl
7.00 x 15.0 x 12.0

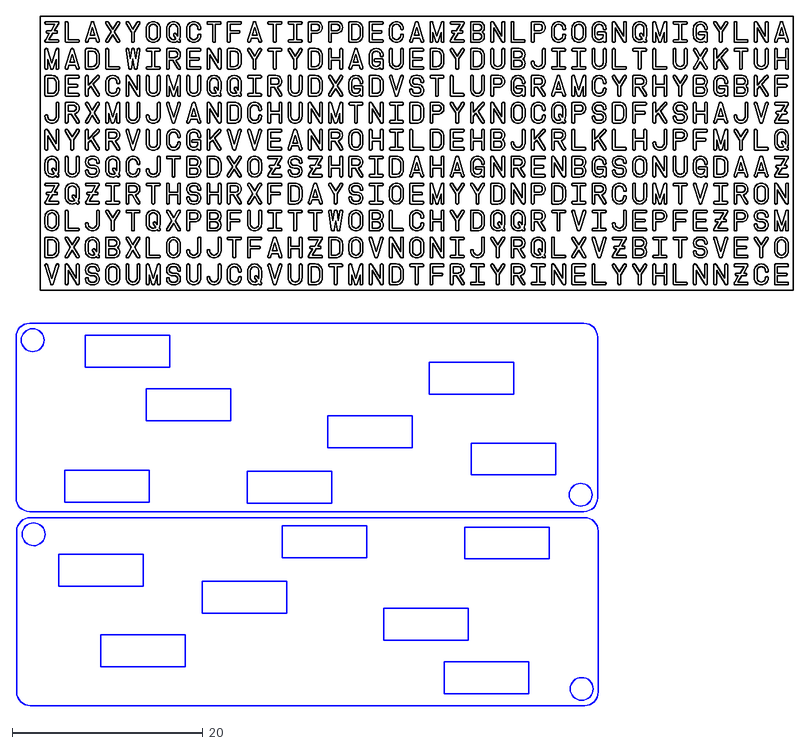
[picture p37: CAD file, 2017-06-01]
Letter_Panel/Grid/letter_grid.dxf
81.4 x 72.2

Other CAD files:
Cipher_Gears/Individual_Gears/6_spoke_3.5_inch.dxf
Letter_Panel/Inner/latch_test.dxf
Letter_Panel/Mask/letter_mask.dxf
Magnet_Grid/Internal/wire_route.dxf
Cipher_Gears/Individual_Gears/2_spoke_3.5_inch.dxf
Cipher_Gears/Individual_Gears/3_spoke_3.5_inch.dxf
Cipher_Gears/Individual_Gears/4_spoke_3.5_inch.dxf
Cipher_Gears/Individual_Gears/5_spoke_3.5_inch.dxf
Drawers/Center/center_drawer.dxf
Drawers/Center/center_latch.skp
Drawers/Center/guide.stl
Drawers/Center/slider.stl
Drawers/Key/key.dxf
Drawers/Key/key_mechanism.skp
Drawers/Key/servo_bracket.stl
Drawers/Right/catch.skp
Drawers/Right/right_drawer.dxf
Letter_Panel/Inner/mask_plate.dxf
Letter_Panel/Mask/Old/latch_test.dxf
Letter_Panel/Mask/Old/mask_plate.dxf
Peg_Board/peg_board.dxf
Peg_Board/peg_board_middle_layer.dxf
Rendering/Full_Rendering.skp
Screw_Panel/screw_plate.dxf

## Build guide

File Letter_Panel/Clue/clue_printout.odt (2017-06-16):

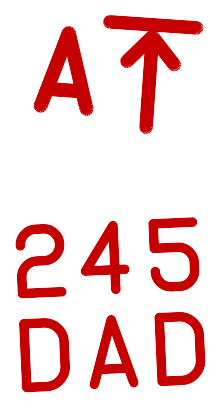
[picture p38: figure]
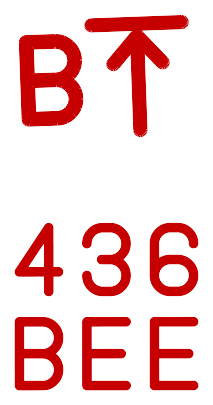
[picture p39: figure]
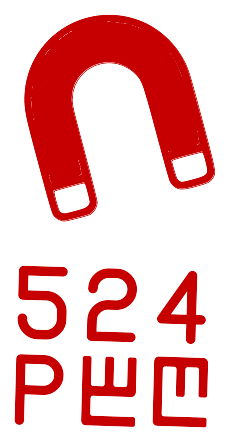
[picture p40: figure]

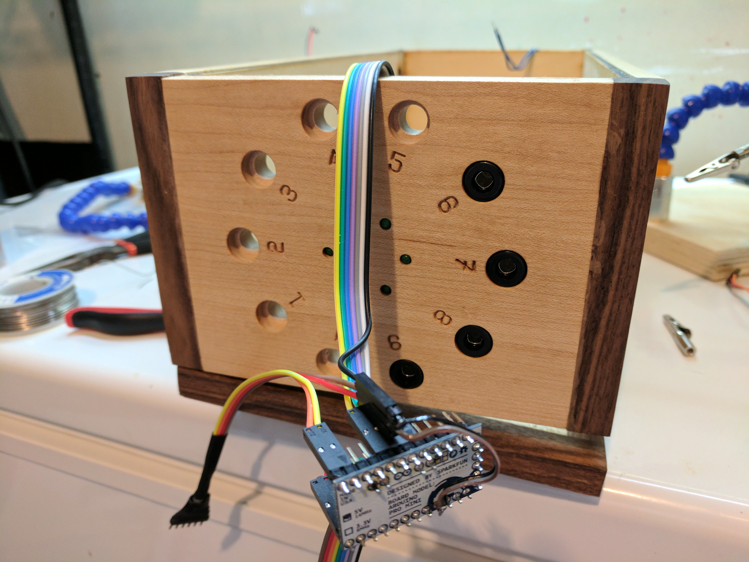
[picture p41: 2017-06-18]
Process/Images/32_Wiring_peg_board.jpg

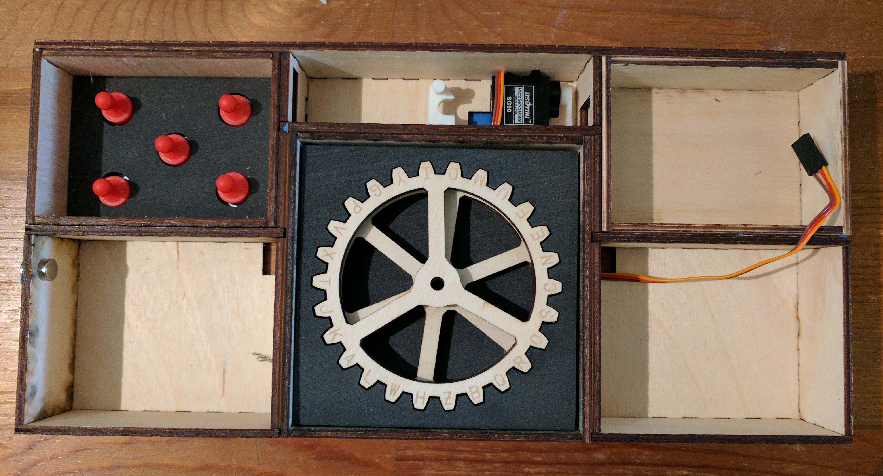
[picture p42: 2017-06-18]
Process/Images/08_Drawer_assembly.jpg

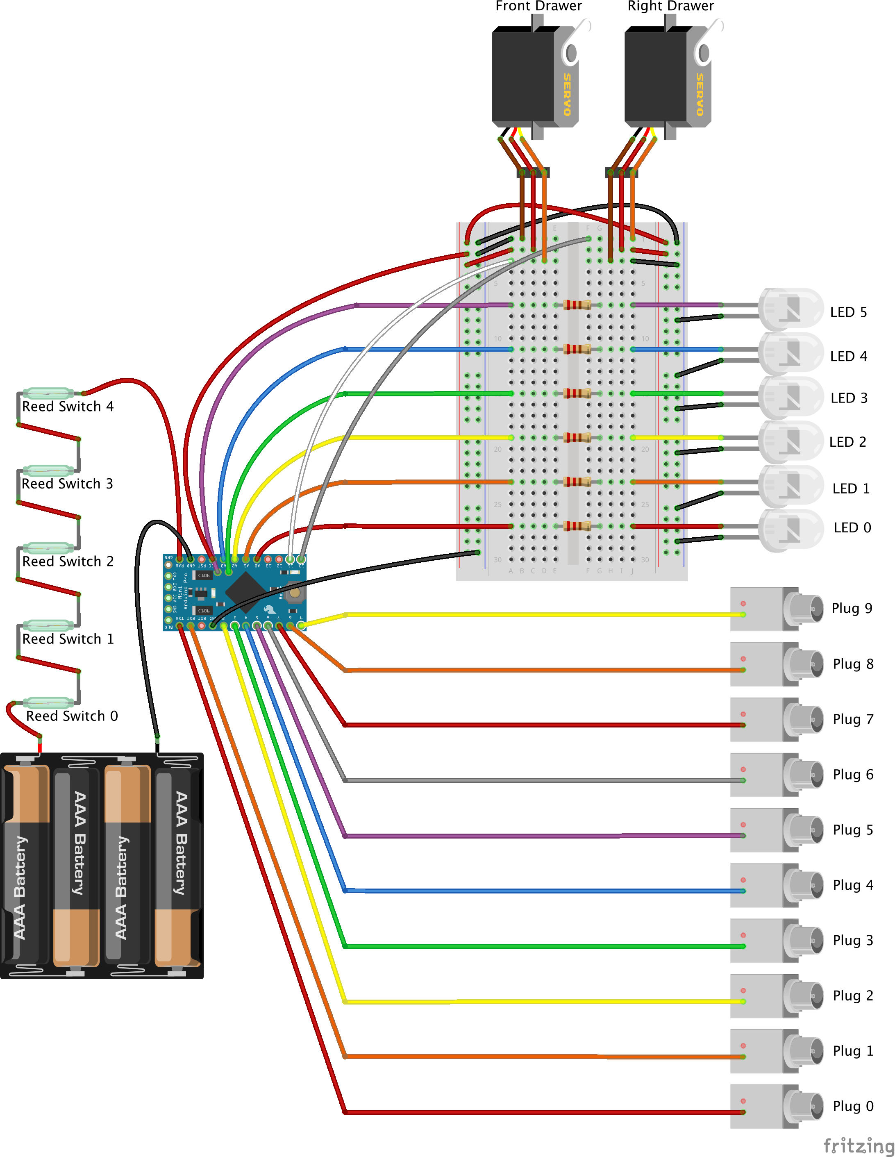
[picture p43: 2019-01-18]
Arduino/Wiring_Schematic.png

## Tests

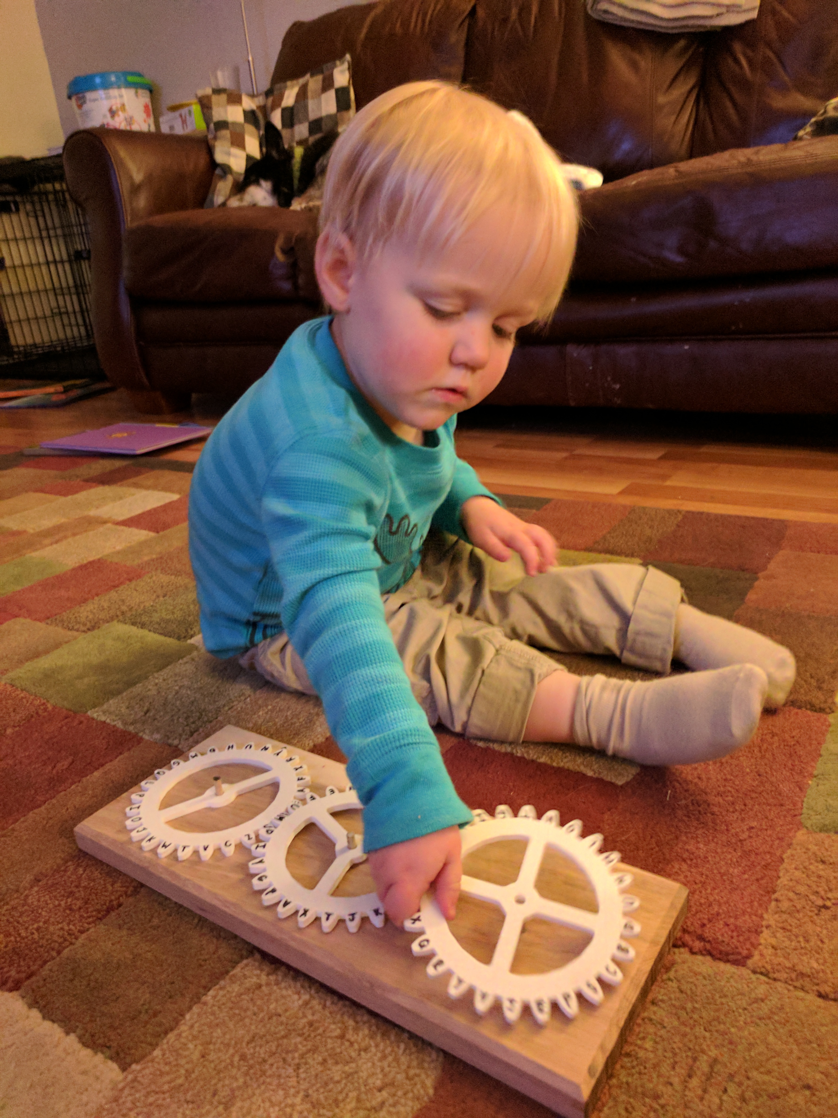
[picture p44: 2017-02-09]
Process/Images/03_Gordon_testing.jpg

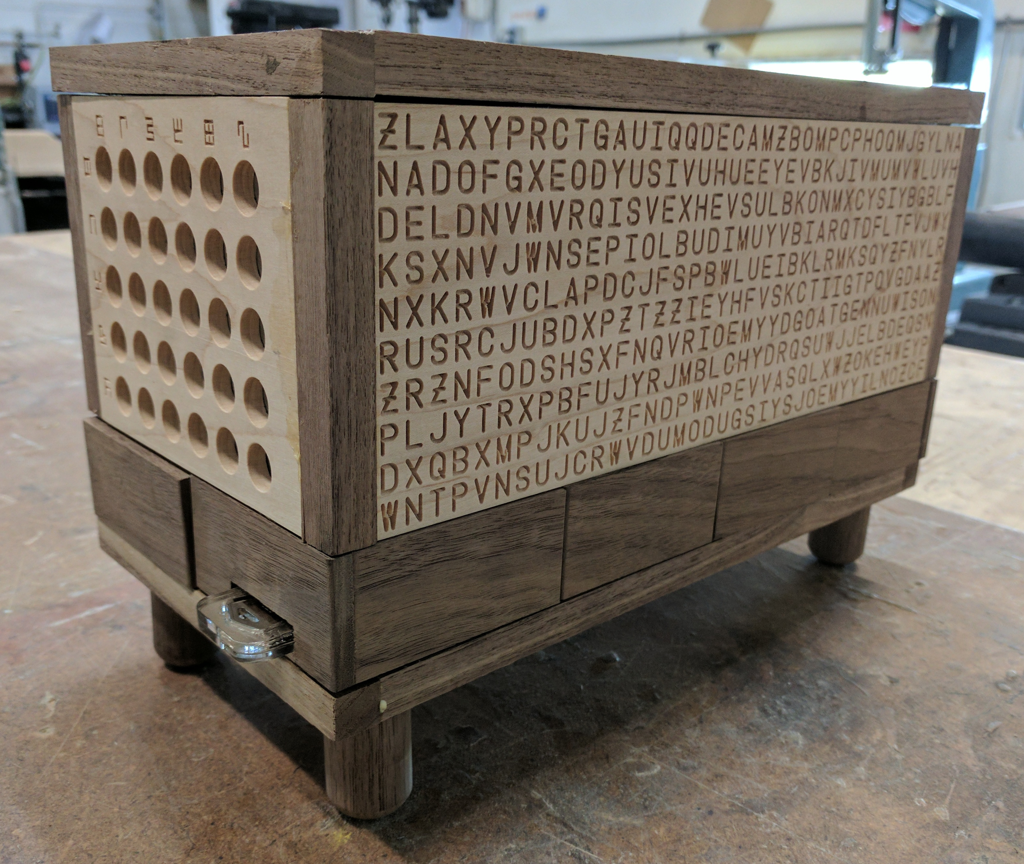
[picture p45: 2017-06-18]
Process/Images/29_Test_fit_entire_box.jpg

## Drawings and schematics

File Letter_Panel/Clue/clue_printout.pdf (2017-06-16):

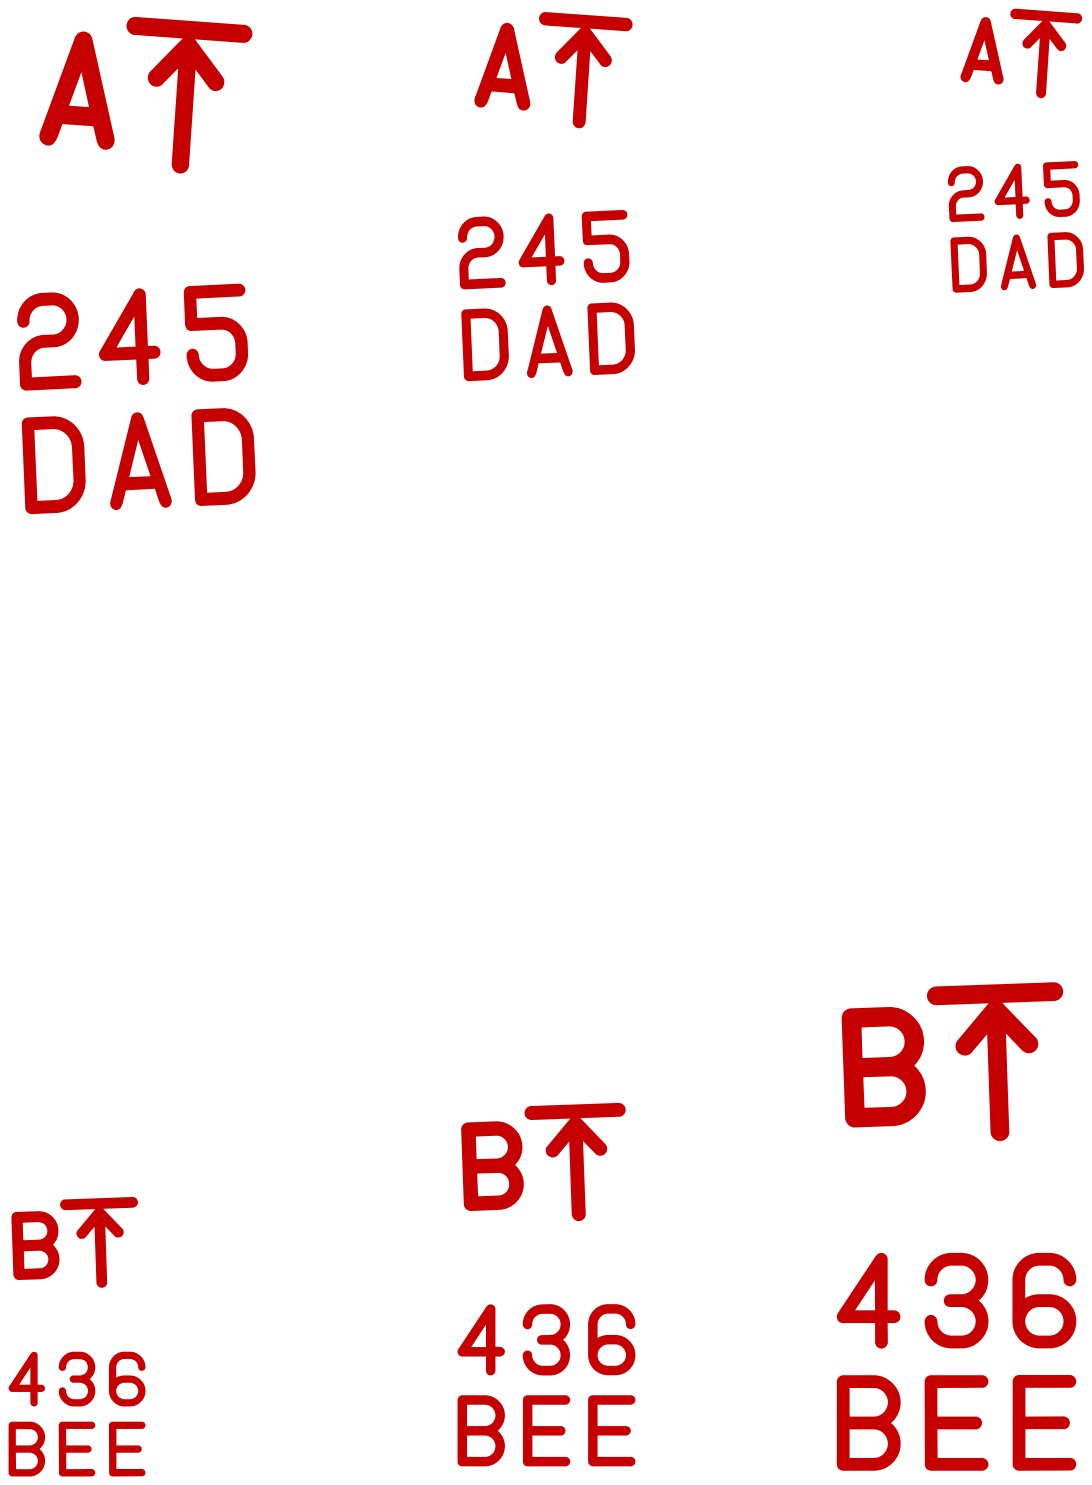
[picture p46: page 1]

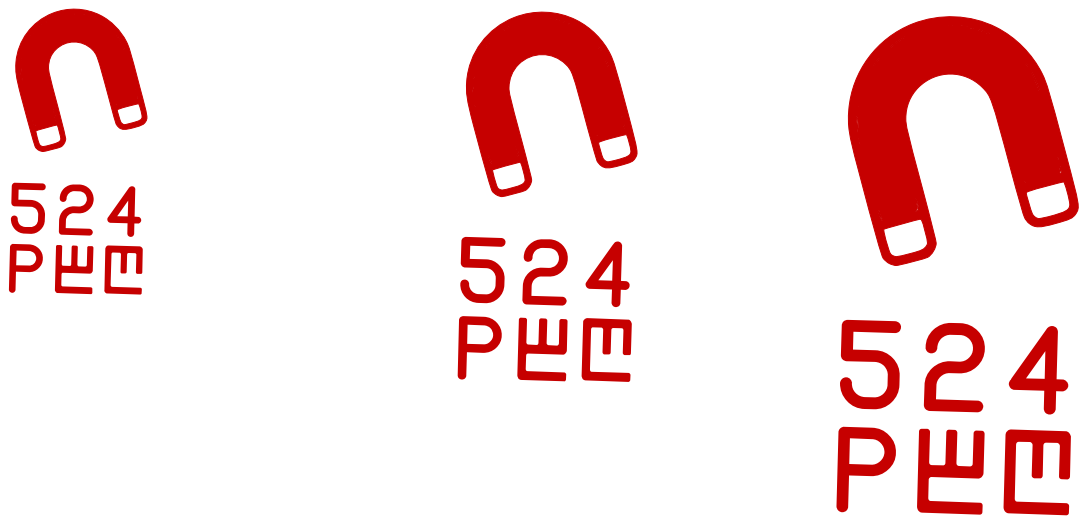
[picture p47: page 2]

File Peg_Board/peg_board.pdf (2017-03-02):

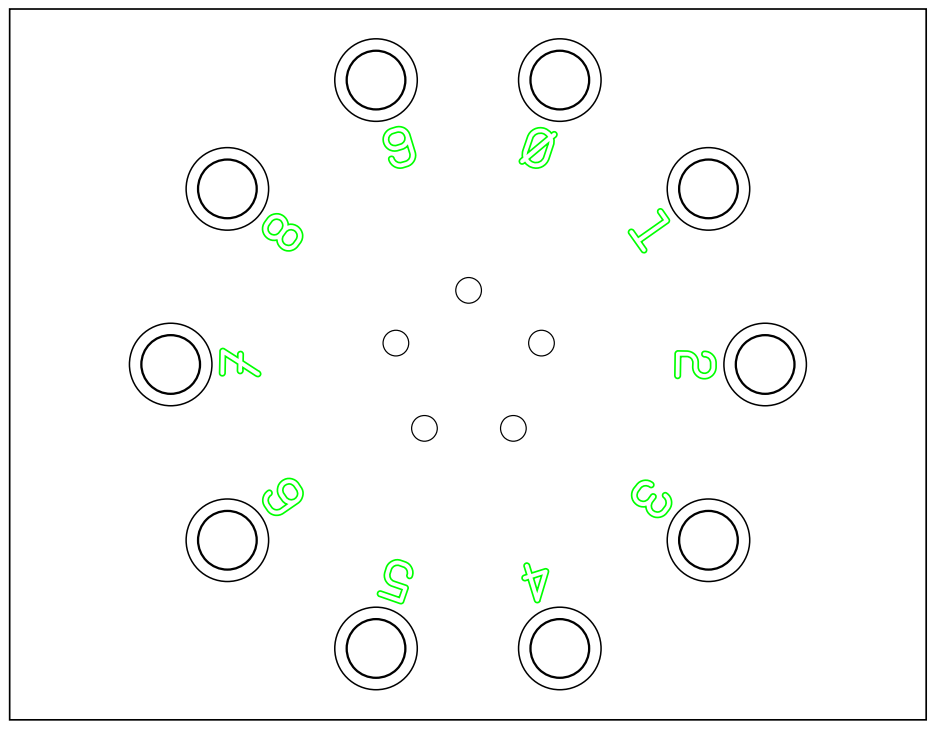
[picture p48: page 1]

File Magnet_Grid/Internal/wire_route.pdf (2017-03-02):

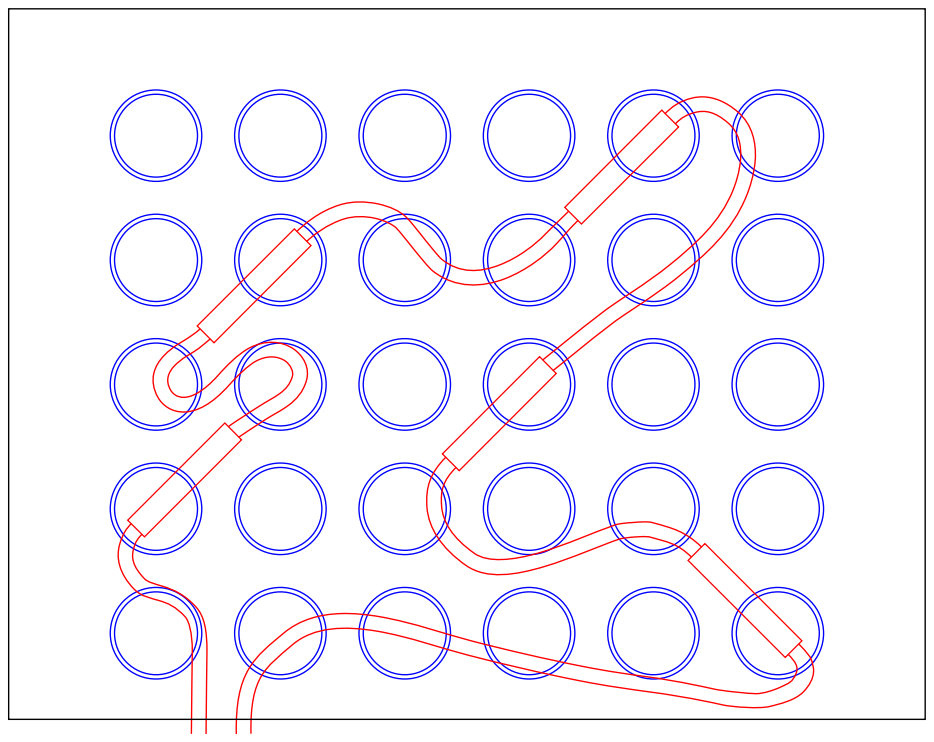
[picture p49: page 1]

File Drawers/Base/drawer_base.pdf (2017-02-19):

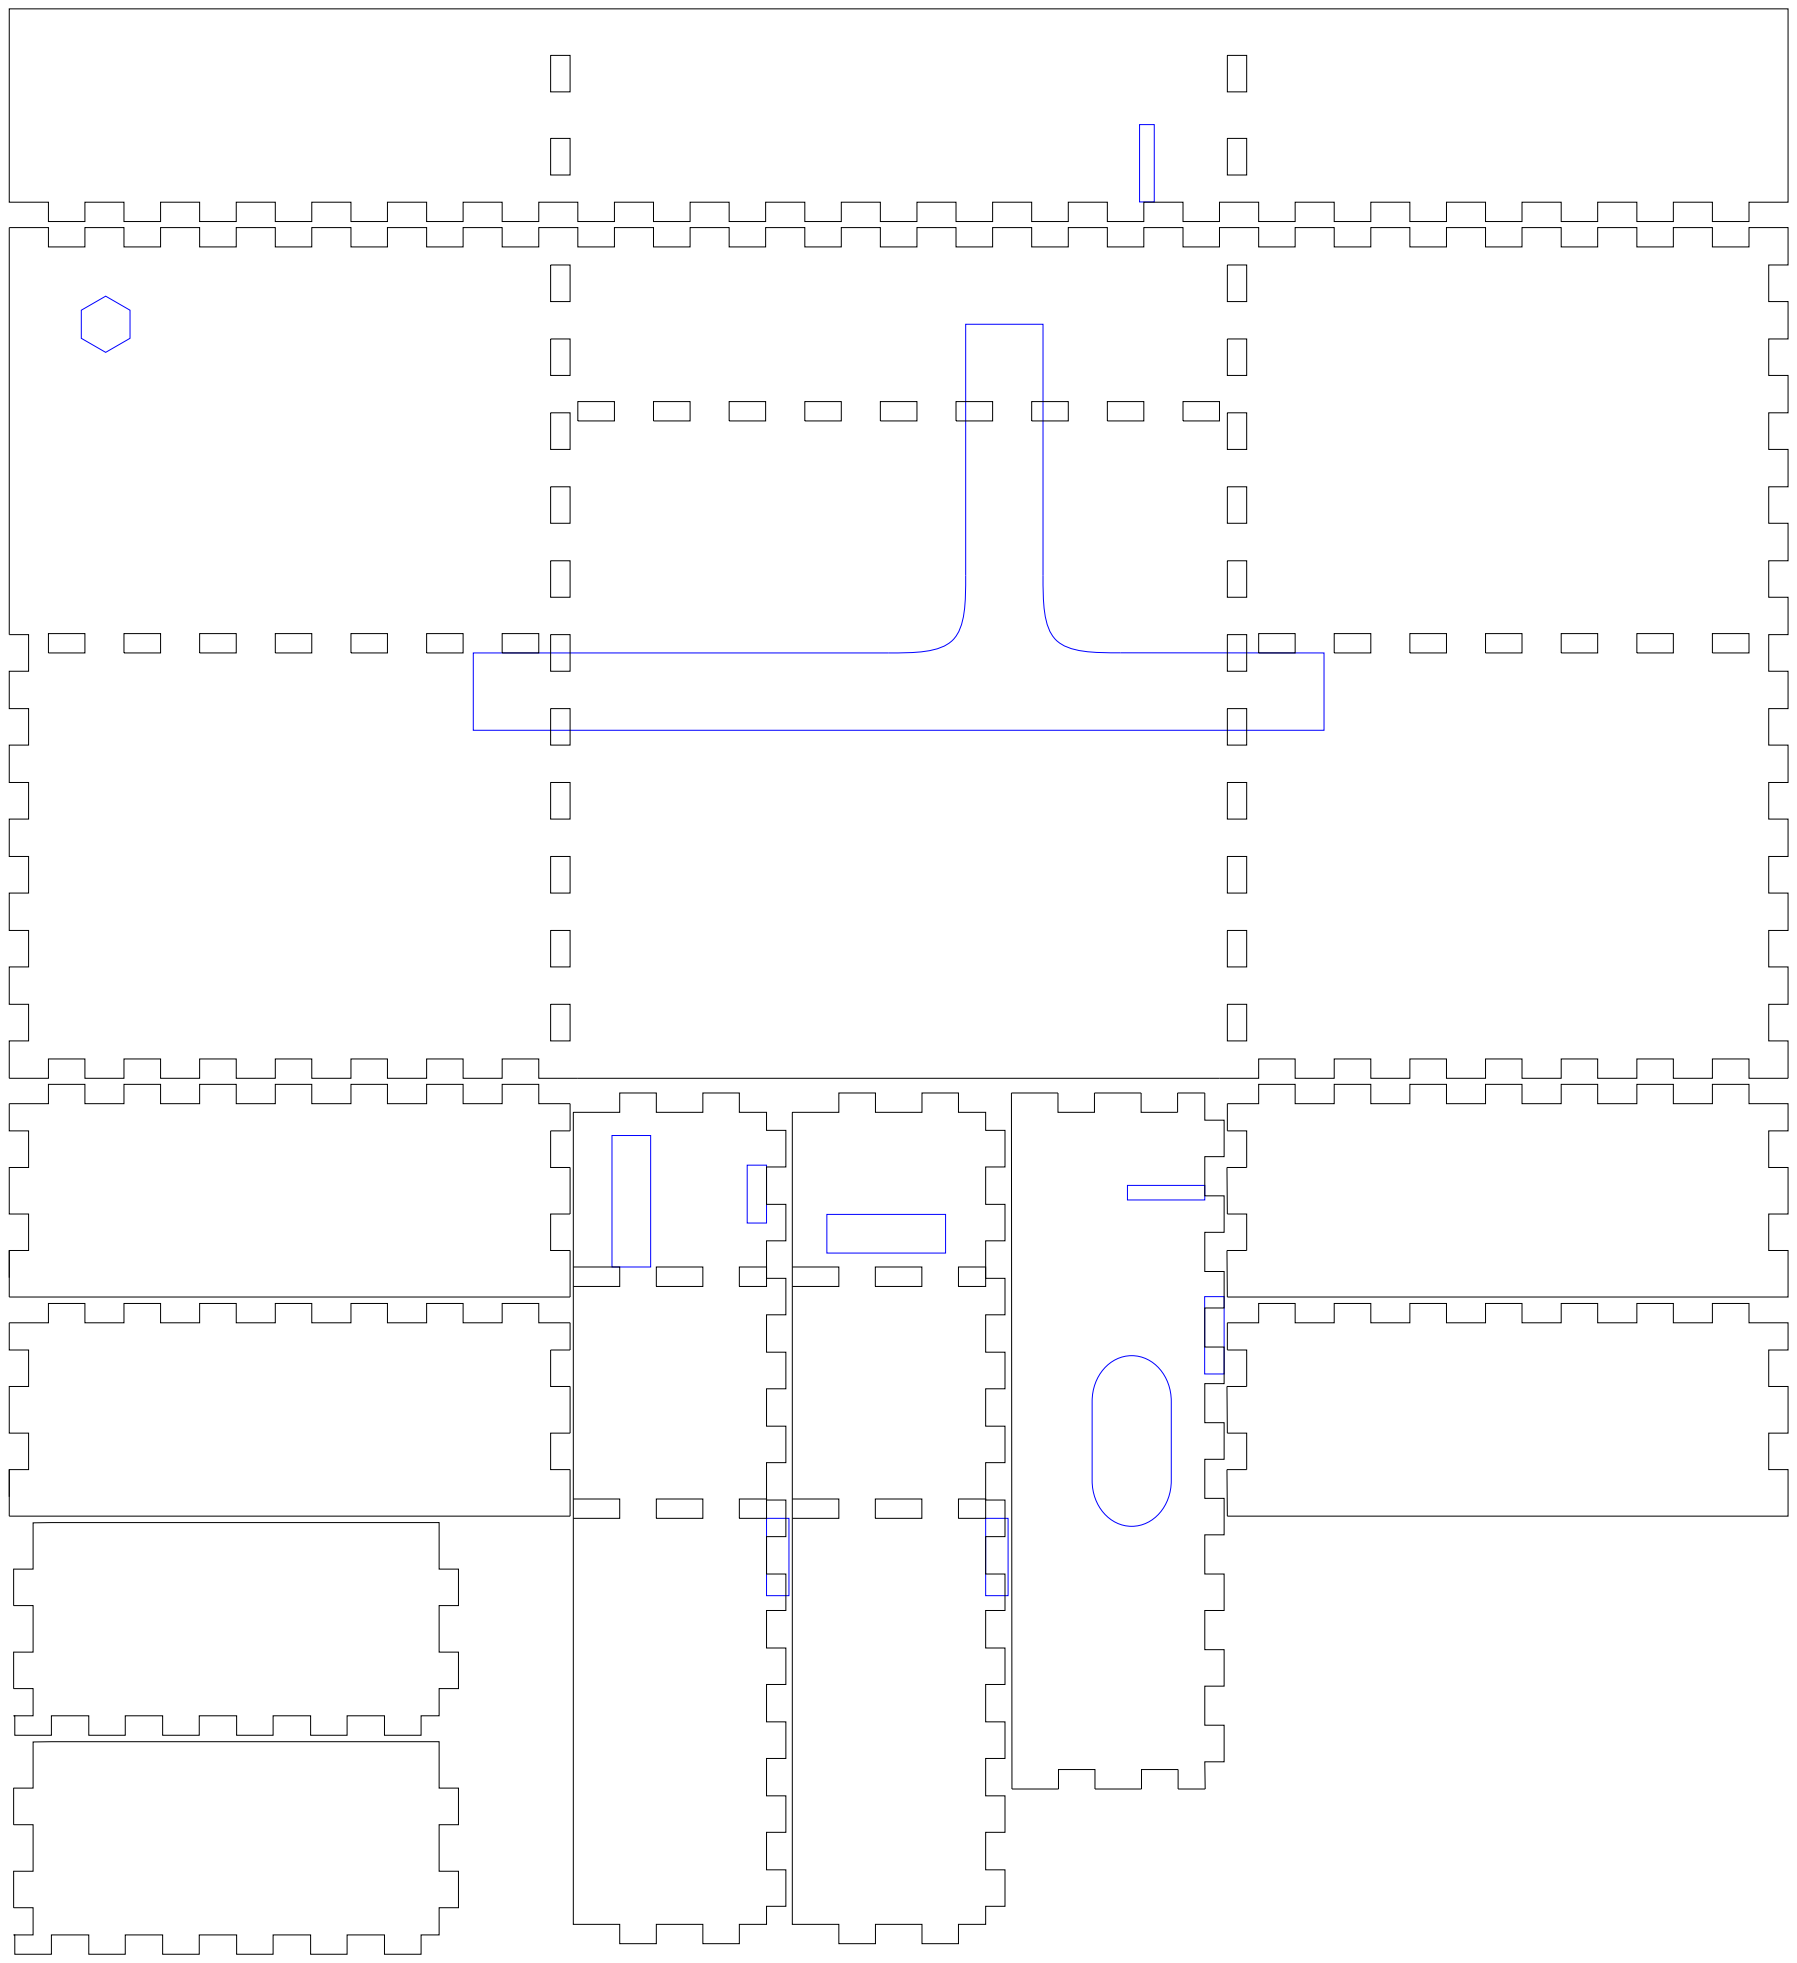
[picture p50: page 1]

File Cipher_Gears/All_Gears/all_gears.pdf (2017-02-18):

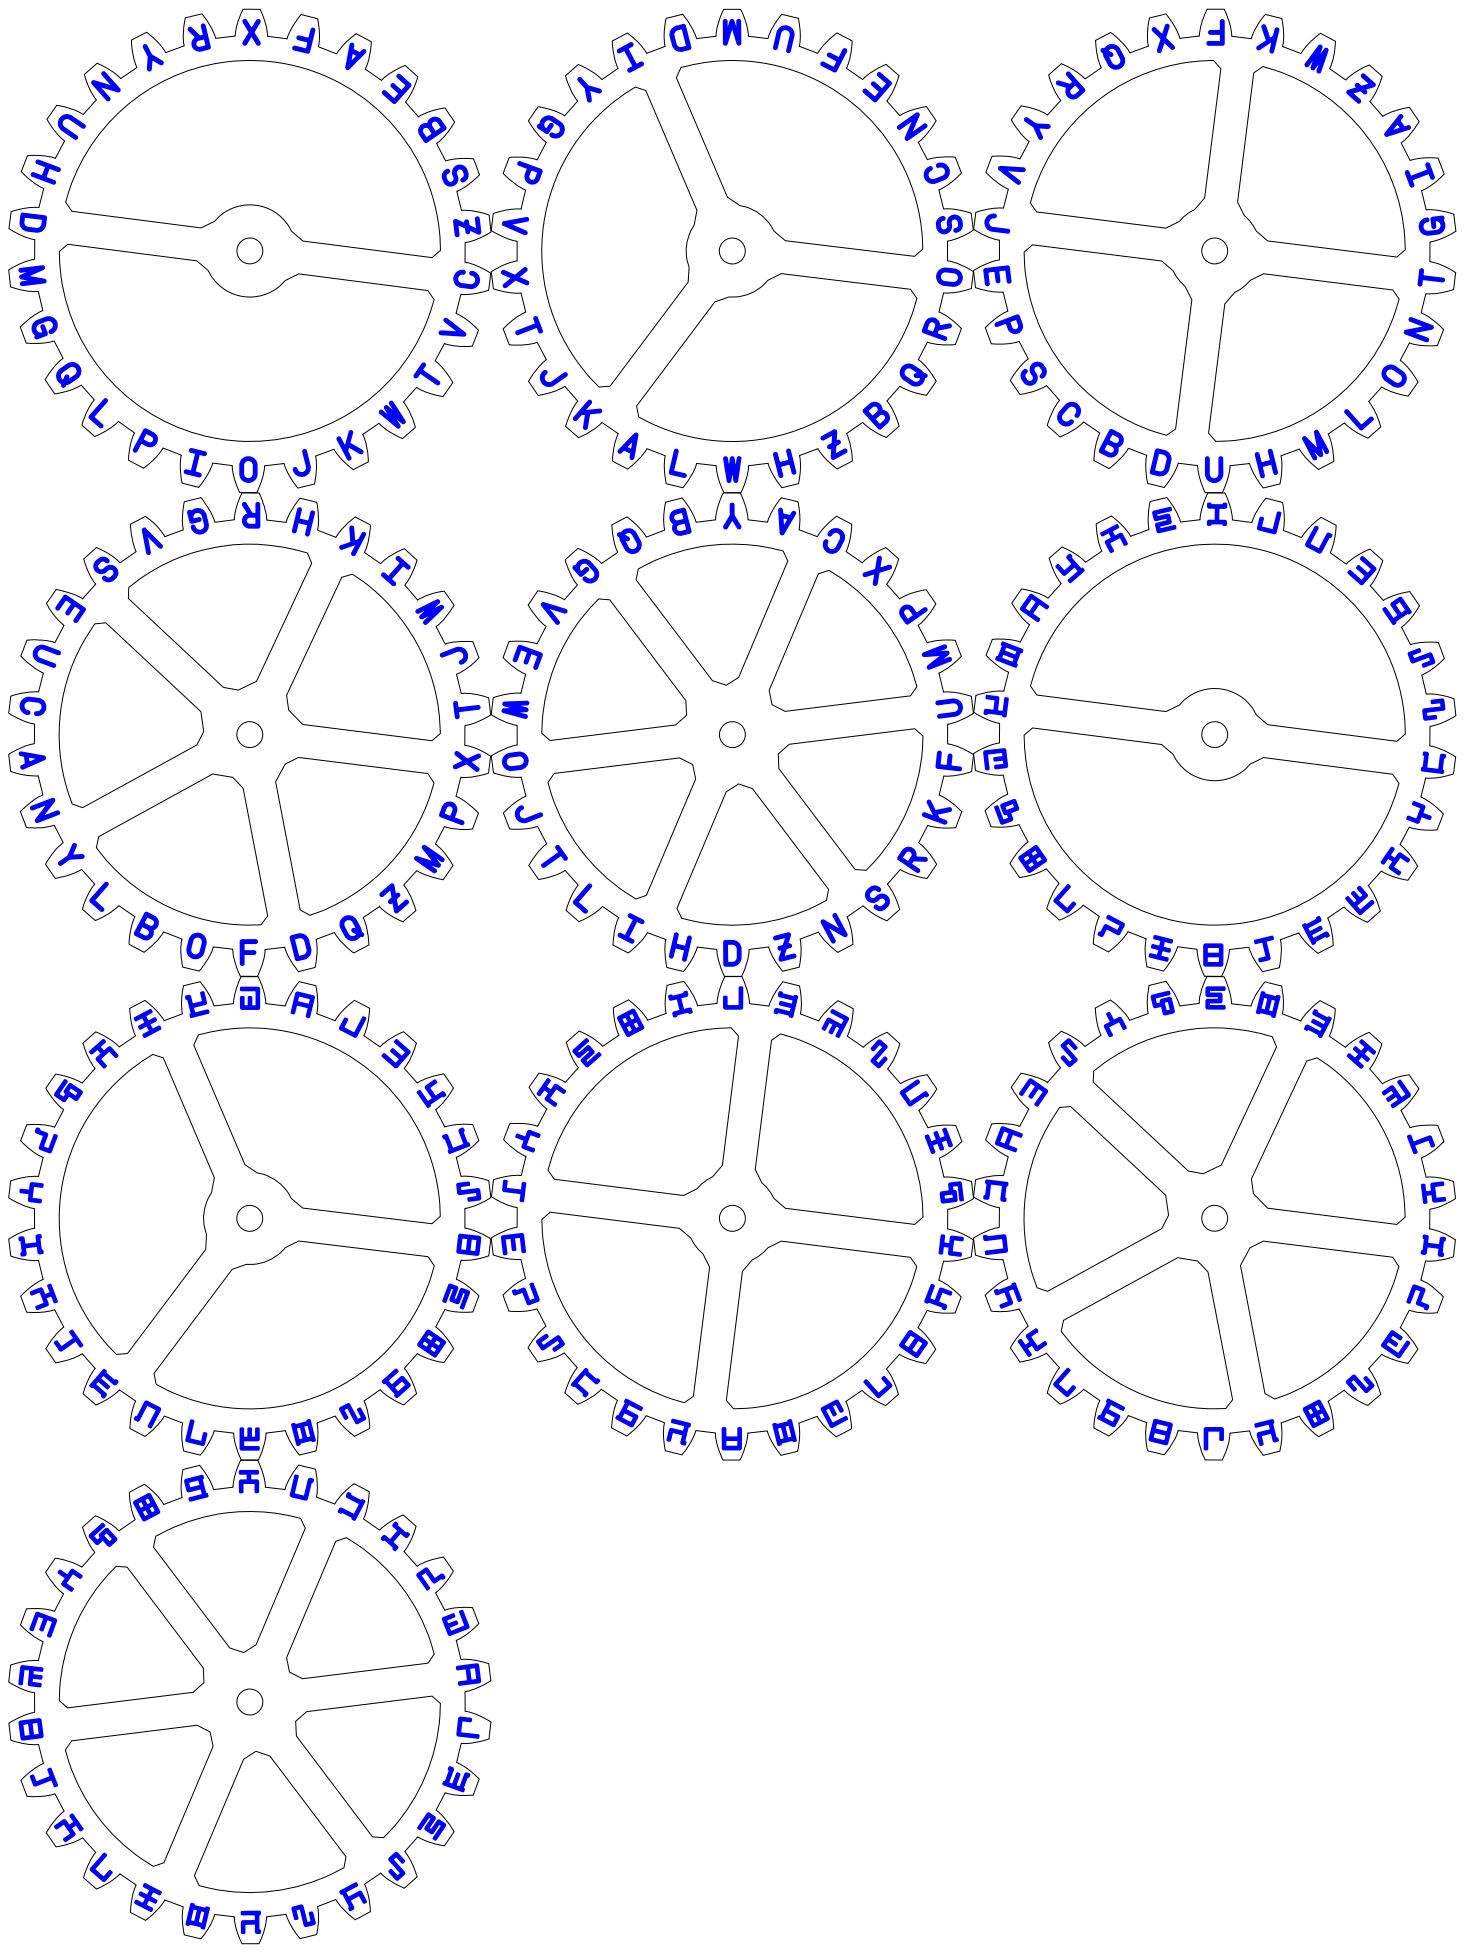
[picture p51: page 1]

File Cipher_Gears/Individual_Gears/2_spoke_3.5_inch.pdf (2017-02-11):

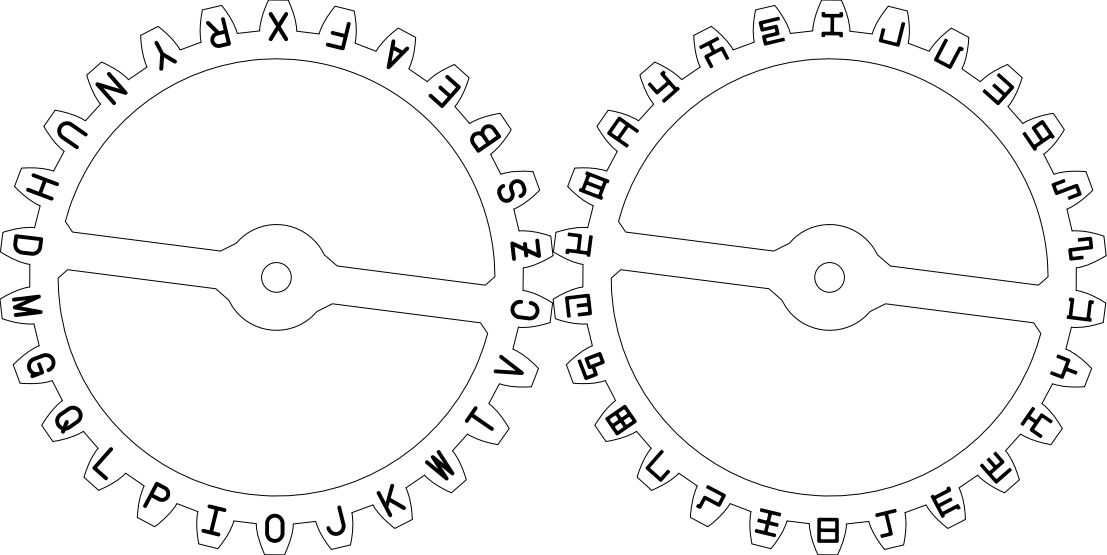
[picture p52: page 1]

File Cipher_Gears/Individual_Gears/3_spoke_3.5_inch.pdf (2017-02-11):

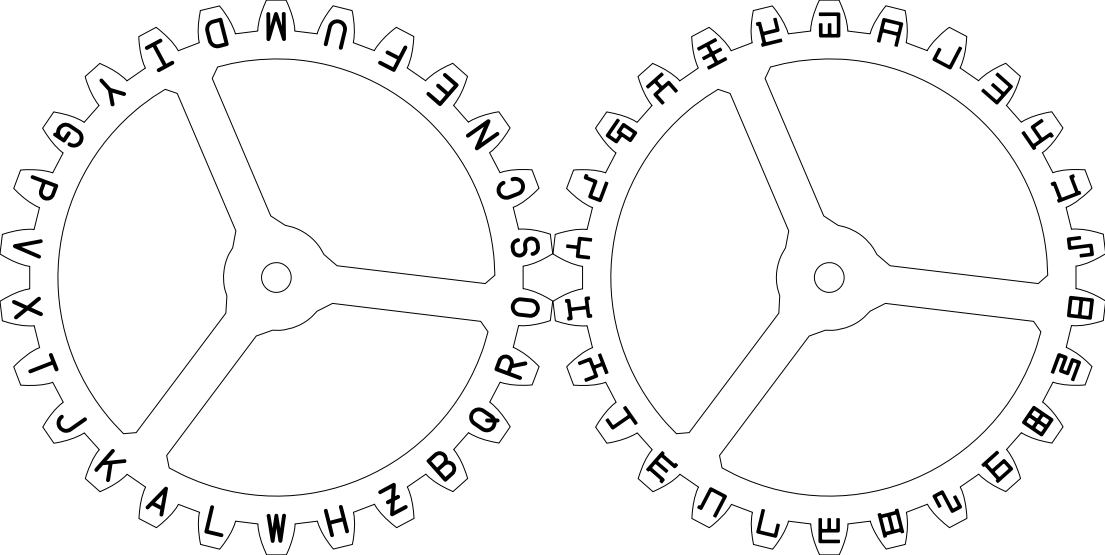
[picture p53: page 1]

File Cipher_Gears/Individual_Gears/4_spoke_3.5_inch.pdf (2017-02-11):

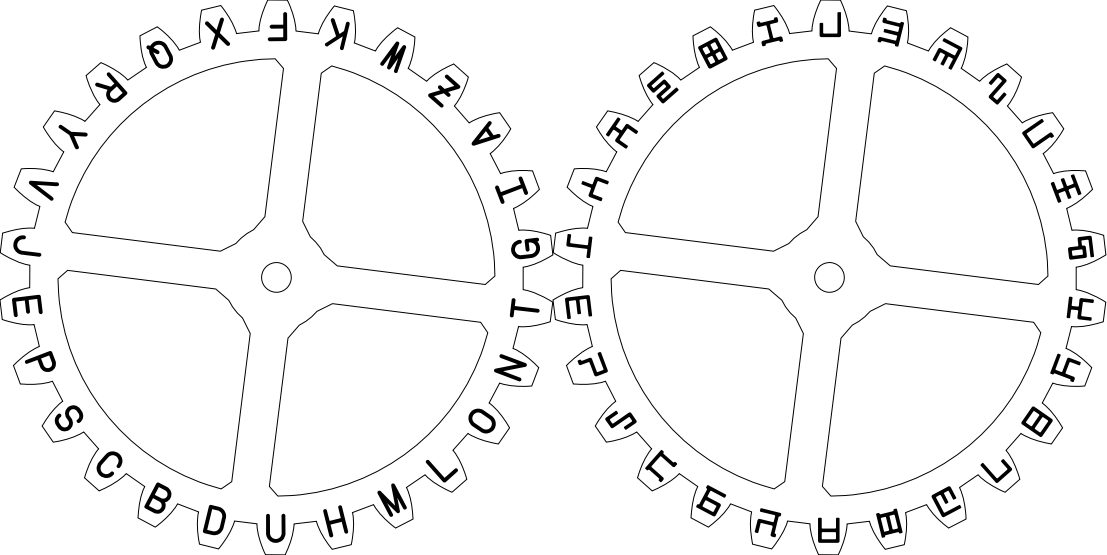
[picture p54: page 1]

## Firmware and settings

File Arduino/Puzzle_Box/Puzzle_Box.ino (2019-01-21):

#include <Servo.h>
#include "PegBoard.h"
#include "Connection.h"

#define INPUT_PULLUP 0x2
#define OPEN LOW
#define CLOSED HIGH

// Initialize the PegBoard
//   Specify the pins for the peg board connectors
//   NOTE: If using pins 0 and 1, we can't do serial communication at the same time.
const byte pegCount = 10;
const byte pegPins[pegCount] = { 0, 1, 2, 3, 4, 5, 6, 7, 8, 9 };
PegBoard pegBoard = PegBoard(pegCount, pegPins);

// Initialize the Servos
//   Specify the pins for the two servo control lines
// Right drawer servo
const byte rightDrawerServoPin = 10;
const int rightDrawerRange[2] = {1000, 2200}; // will likely have to fiddle with these values per servo
// Key drawer servo
const byte keyDrawerServoPin = 11;
const int keyDrawerRange[2] = {800, 2125};    // will likely have to fiddle with these values per servo
// Only use one Servo object, and connect/disconnect as needed.
// We're never controlling both simultaneously.
Servo servo;

// Initialize the LEDs
//   Specify the pins for the pegboard LEDs
const byte ledCount = 6;
const byte ledPins[ledCount] = { A0, A1, A2, A4, A3, A5 };

// Define our peg board combinations
const Connection pegCombos[ledCount] = {
    // Here are the expected combinations, and their order
    // NOTE: The nature of this pegboard makes it impossible
    //       to require a connection between the same digits
    //       (e.g. You can never wire up 2--2)
    // Change these (obviously) to the combinations you would like to use.
    Connection(0,1),
    Connection(0,2),
    Connection(0,3),
    Connection(0,4),
    Connection(0,5),
    Connection(0,6)
    // That's the kind of thing an idiot would have on their luggage!
    // https://www.youtube.com/watch?v=_JNGI1dI-e8
};

// How many combinations have we solved thusfar
byte progress = 0;

void setup() {
  // Enable serial connection - Note: when using pins 0 or 1 for anything else, this won't work.
  //Serial.begin(9600);

  // Enable peg board
  pegBoard.begin();

  // Set all LED pins as OUTPUT
  for (byte j=0; j<ledCount; j++) {
    pinMode(ledPins[j],OUTPUT);
  }
  
  // On power up, we want this drawer to open
  openRightDrawer();
}

void loop() {
  // Check if there are connections
  if (pegBoard.hasNewConnection()) {
    Connection conn = pegBoard.getConnection();
    conn.print();
    // New connection matches expected combination
    if (conn == pegCombos[progress]) {
      Serial.print("  Good connection! Lock ");
      Serial.print(progress+1);
      Serial.println(" disabled.");
  
      // Light up an LED
      Serial.print("LED ");
      Serial.print(progress+1);
      Serial.println(" on.");
      digitalWrite(ledPins[progress],HIGH);
  
      // Move forward in the combination
      progress++;
  
      // We've connected all the peg pairs
      if (progress >= ledCount) {
        Serial.println("Access granted.");

        // Flash all LEDs a few times
        for (int j=0; j<=5; j++) {
          for (int i=0; i<ledCount; i++) {
            digitalWrite(ledPins[i],LOW);
          }
          delay(250);
          for (int i=0; i<ledCount; i++) {
            digitalWrite(ledPins[i],HIGH);
          }
          delay(250);
        }

        // Open the key drawer
        openKeyDrawer();
      }
    }
    // Bad connection - reset progress
    else {
      Serial.println("  Bad connection. All locks resetting.");

      // Turn off all LEDs in reverse order
      for (int i=progress-1; i>=0; i--) {
        // Turn an LED off
        Serial.print("LED ");
        Serial.print(i+1);
        Serial.println(" off.");
        digitalWrite(ledPins[i],LOW);
        delay(500);
      }
        
      // If the box had been solved, and an incorrect connection is made,
      // move the servos back to their starting positions to reset the box.
      if (progress >= ledCount) {
        Serial.println("Resetting servos...");
        // Close the drawers
        resetServos();
      }

      // Reset progress to 0
      progress = 0;
    }
  }  
}

// Causes the servo to move such that the right drawer opens
void openRightDrawer(){
  Serial.println("Opening right drawer");
  moveServo(rightDrawerServoPin, 180, rightDrawerRange);
}
// Causes the servo to move such that the right drawer closes
void closeRightDrawer(){
  Serial.println("Closing right drawer");
  moveServo(rightDrawerServoPin, 130, rightDrawerRange);
}

// Causes the servo to move such that the key drawer opens
void openKeyDrawer(){
  Serial.println("Opening key drawer");
  moveServo(keyDrawerServoPin, 180, keyDrawerRange);
}
// Causes the servo to move such that the key drawer opens
void closeKeyDrawer(){
  Serial.println("Closing key drawer");
  moveServo(keyDrawerServoPin, 0, keyDrawerRange);
}

// Causes the servo to move such that the right drawer closes
void resetServos(){
  Serial.println("Closing both drawers");
  closeRightDrawer();
  closeKeyDrawer();
}

/*
 * Moves the specified servo to the requested degree position.
 * Requires the specification of min/max values.
 * Attaches to the servo, moves it, and detaches. This means that
 * the servo won't hold its position, but also won't jitter
 * or continue to draw battery. This was sufficient for this use.
 */
void moveServo(byte servoPin, int position, const int range[]) {
  // Write first, to avoid jumping
  servo.write(position);
  // Connect, causing the servo to move to the position written earlier
  servo.attach(servoPin, range[0], range[1]);
  // Give the servo some time to get where it's going
  delay(500);
  // Disconnect from the servo, to save battery and avoid jitter
  servo.detach();
}

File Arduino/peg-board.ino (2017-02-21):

#include <Keypad.h>
#include "PegBoard.h"
#include "Connection.h"

#define INPUT_PULLUP 0x2
#define OPEN LOW
#define CLOSED HIGH

// Initialize the PegBoard
const byte pegCount = 10;
const byte pegPins[pegCount] = { 2, 3, 4, 5, 6, 7, 8, 9, 10, 11 };
pegBoard = PegBoard(pegCount, pegPins);

// Initialize the LEDs
const byte ledCount = 5;
const byte ledPins[ledCount] = { A0, A1, A2, A3, A4 };

// Initialize the success and failure sounds
byte successSoundPin = 13;
byte failureSoundPin = 12;

// Set up our combinations
const byte pegCombo[ledCount][2] = {
  Connection(1,7),
  Connection(1,7),
  Connection(3,5),
  Connection(2,8),
  Connection(4,9),
  Connection(0,6)
};

// How many combinations have we solved thusfar
byte progress = 0;



void setup() {
  // Enable serial connection
  Serial.begin(9600);

  // Set all peg pins with pull-up resistance (high, unless pulled to ground)
  for (byte i=0; i<pegCount; i++) {
    pinMode(pegPins[i],INPUT_PULLUP);
  }

  // Set all LED pins as OUTPUT
  for (byte j=0; j<ledCount; j++) {
    pinMode(ledPins[j],OUTPUT);
  }

  // Sound system
  pinMode(successSoundPin, OUTPUT);
  pinMode(failureSoundPin, OUTPUT);
}

void loop() {
  // Check if there are connections
  if (pegBoard.hasNewConnection()) {
    conn = pegBoard.getConnection();
    conn.print();
    if (conn.isConnected()) {
      // New connection matches expected combination
      if (conn == pegCombos[progress]) {
        Serial.print("  Good connection! Lock ");
        Serial.print(progress+1);
        Serial.println(" disabled.");
  
        // Light up an LED
        Serial.print("LED ");
        Serial.print(progress+1);
        Serial.println(" on.");
        digitalWrite(ledPins[progress],HIGH);
  
        // Move forward in the combination
        progress++;
  
        // We've connected all the peg pairs
        if (progress >= ledCount) {
          Serial.println("Access granted.");
          
          // Play a success sound
          digitalWrite(successSoundPin,HIGH);
          delay(100);
          digitalWrite(successSoundPin,LOW);
        }
      }
      // Bad connection - reset progress
      else {
        Serial.println("  Bad connection. All locks resetting.");
            
        // Turn off all LEDs.
        for (int i=progress; i>=0; i--) {
          // Play failure sound
          digitalWrite(failureSoundPin,HIGH);
            
          // Turn an LED off
          Serial.print("LED ");
          Serial.print(i+1);
          Serial.println(" off.");
          digitalWrite(ledPins[progress],LOW);
          delay(500);

          // Stop failure sound
          digitalWrite(failureSoundPin,LOW);
        }

        // Reset progress to 0
        progress = 0;
      }
    }
  }
}

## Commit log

2017-02-09 Adding to version control
    [2-spoke-3.5-inch.dxf, 3-spoke-3.5-inch.dxf, 4-spoke-3.5-inch.dxf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]
2017-02-09 Gears will be two laminated layers, not two-sided
2017-02-09 Adding a laser power/speed test
2017-02-09 Wider margins for box edges
    [Full-Rendering.skp]
2017-02-11 Major rearranging
    [2-spoke-3.5-inch.dxf, 3-spoke-3.5-inch.dxf, 4-spoke-3.5-inch.dxf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]
2017-02-12 Adding magnet grid plans
    [magnet_grid.dxf]
2017-02-13 Adding clue, some cleanup
    [magnet_grid.dxf]
2017-02-16 Magnet grid alignment
2017-02-16 Making directories by material
2017-02-16 Corrected volumes for 8ohm speaker
2017-02-16 Addition to guide to prevent twisting
    [Guide.stl, Latch.skp]
2017-02-16 Holes no longer filled
    [Guide.stl, Latch.skp]
2017-02-16 Adding initial Arduino sketch
    [Latch.skp]
2017-02-18 With layers understood by LaserCut 5.3
    [magnet_grid.dxf, magnet_grid_for_cut.dxf]
2017-02-18 Re-drawn with layers
    [gear-cutout.dxf, laser-test.dxf, left_rectangular_drawer.dxf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]
2017-02-19 Laser-cut drawer base added
    [drawer_base.dxf]
2017-02-19 Now with servos and limit switches
    [Full-Rendering.skp]
2017-02-20 Sketch for peg-board puzzle
2017-02-20 Some updates with speaker
    [Full-Rendering.skp]
2017-02-21 First peg-board puzzle prototype
2017-02-23 Lights weren't turning off with wrong combination
    [peg-board.ino]
2017-03-02 DXF in correct units for ShopBot
    [magnet-grid-internal.dxf, magnet_grid_for_cut.dxf]
2017-03-02 DXF in correct units for LaserCut 5.3
    [drawer_base.dxf]
2017-03-02 Removing old LaserCut 5.3 project
2017-03-02 Be consistent in file naming
    [drawer-base.dxf]
2017-03-02 Rendering now has speaker
    [Full-Rendering.skp]
2017-03-02 Moving latch to Drawer directory
    [Guide.stl, Hook.stl, Latch.skp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]
2017-03-02 Consistent file naming convention
    [2_spoke_3.5_inch.dxf, 3_spoke_3.5_inch.dxf, 4_spoke_3.5_inch.dxf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]
2017-03-05 Moving servo mount, widening limit switch slots
    [drawer_base.dxf]
2017-03-05 Now includes extra screw hole, limit switch mount
    [Guide.stl]
2017-03-05 With rack/pinion addition
    [pinion_gear.dxf]
2017-03-05 Unhiding components
    [Full_Rendering.skp]
2017-03-05 Correcting hole that wasn't a hole
    [Full_Rendering.skp, Guide.stl]
2017-03-08 units were incorrect
    [gear_cutout.dxf]
2017-03-08 adding slot underneath for latch slider
    [left_rectangular_drawer.dxf]
2017-03-08 correct DXF units
    [drawer_base.dxf]
2017-03-11 Adding peg board toolpaths
2017-03-11 Larger spacing between numbers and holes
    [peg_board.dxf]
2017-03-14 Epoxy Inlay test
    [inlay_test.dxf]
2017-03-14 Adding toolpaths for ShopBot
    [peg_board.dxf]
2017-03-17 Adding inner slider mechanics
    [mask_plate.dxf]
2017-03-19 First cut at peg board wire routing
    [peg_board_middle_layer.dxf]
2017-03-19 Magnet grid ShopBot files
2017-03-19 Inlay test
    [inlay_test_mm.dxf]
2017-03-21 Sliding mask plate in correct units, key hole larger
    [mask_plate.dxf]
2017-03-21 Removed unusable file
    [inlay_test_mm.dxf]
2017-03-21 Start on lasercut wire routing
    [peg_board_middle_layer.dxf]
2017-04-09 Mechanical iris, ready for cut
    [mechanical_iris.dxf]
2017-04-09 Testing latch actuated by servo
    [latch_test.dxf]
2017-05-31 Catching up
    [latch_test.dxf, mechanical_iris.dxf]
2017-06-01 Correcting for thicker material
2017-06-01 Centered letters more correctlyMagnet_Grid/External/magnet_grid_external.crv
2017-06-01 Changed from 5 to 6 LEDs
    [peg_board.dxf]
2017-06-01 New toolpaths for thicker material
2017-06-01 Class for encrypt/decrypt with gears
2017-06-01 Mask plate test code
2017-06-01 Letter grid layout, with mask plate
    [Letter_grid.dxf]
2017-06-03 Moving content around
    [inlay_test.dxf]
2017-06-03 Splitting the grid of letters from the mask
    [letter_grid.dxf, letter_mask.dxf]
2017-06-03 Renaming content
    [wire_route.dxf]
2017-06-03 No longer using this content
    [peg_board_middle_layer.dxf]
2017-06-06 Adding screw panel first attempt
    [screw_plate.dxf]
2017-06-06 Image of key to trace
2017-06-06 Key and sliding drawer
    [key.dxf]
2017-06-06 Shell of box onto which faces attach
    [box_shell.dxf]
2017-06-06 With corrected letters
    [letter_mask.dxf]
2017-06-06 Screw plate rendered for ShopBot
2017-06-06 Paths only
    [box_shell.dxf]
2017-06-07 Inner box taller, peg holes offset and larger
    [box_shell.dxf]
2017-06-07 Renaming Arduino sketch
2017-06-07 3D printed brackets ready
    [key_guide.stl, key_mechanism.skp, latch.skp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]
2017-06-07 Success sound plays on power-up
2017-06-07 Magnet grid re-cut, with 4 inch tall
2017-06-07 With hole for standoff
    [key.dxf]
2017-06-09 Moved some pins, disabled sounds, turned off Serial
    [servo_bracket.stl]
2017-06-12 Set correct open/close servo stops, handles resetting of box
    [Puzzle_Box.ino]
2017-06-12 Test of servos, with serial comm to set angles
2017-06-16 Clues for the letter panel, prepped for printing
2017-06-18 Servos now unpowered after each movement to avoid jitter
    [Puzzle_Box.ino]
2017-06-18 Cleanup of content no longer used
    [laser_test.dxf, mechanical_iris.dxf]
2017-06-18 Box gears image
2017-06-25 Removing content that did not end up being used
    [inlay_test.dxf, peg_board_middle_layer.dxf, pinion_gear.dxf]
2017-06-25 Changes to some dimensions
    [key_guide.stl, key_mechanism.skp]
2018-02-20 Renaming directory structure
    [Guide.stl, Hook.stl, Slider.stl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]
2018-02-20 Adding all-in-one files to streamline build
    [drawers_and_shell.dxf, key_slider.dxf, latches_and_brackets.stl]
2018-03-03 Screenshot of 3D-printed parts
2018-03-03 Changing a tabbed edge to straight
    [drawer_base.dxf, drawers_and_shell_0125_birch_plywood.dxf]
2018-03-03 Laser project files
2018-03-04 Adding CNC files
    [all_box_faces_075_maple.dxf]
2018-03-07 VCarve file for ShopBot
    [all_box_faces_075_maple.dxf]
2018-11-05 Adding schematic
    [PuzzleBox.fzz]
2019-01-13 More comments, fix a function definition
    [Puzzle_Box.ino]
2019-01-18 Updating schematic to show single wire from banana connectors
    [PuzzleBox.fzz]
